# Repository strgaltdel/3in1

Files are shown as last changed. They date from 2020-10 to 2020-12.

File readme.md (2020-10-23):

## 3in1
November 2020

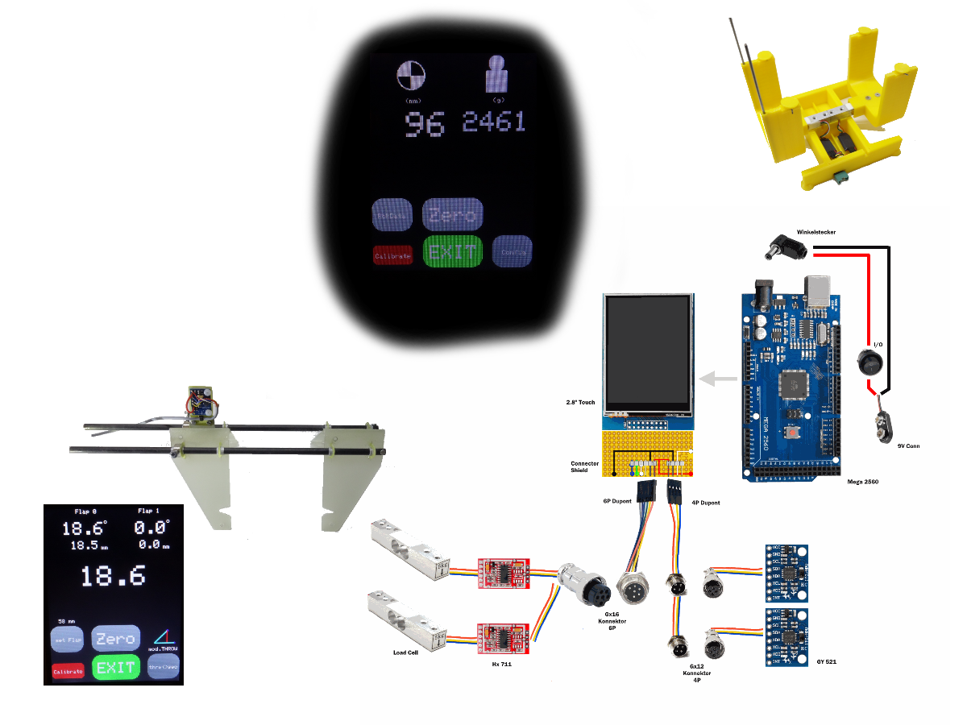
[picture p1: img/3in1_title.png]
3in1 title


### Einführung

"3in1" ist ein Mehrzweck Meßinstrument für den RC Bereich

Basierend auf der Arduino Mega2560 Platform können RC Hobbyisten folgende Werte an Flugmodellen vermessen:

  * Schwerpunkt
  * EWD
  * Ruderausschlag

### Hardware
  
  * Controller
	* Arduino Mega 2560 
  * LCD
	* 2.8" Touch, Adafruit kompatibel
  * Schwerpunkt
	* 2xHX711 basierte Load-cells in 1,2,3 oder 5kg Ausführung
  * EWD
	* GY521 IMU
  * Ruderausschlag
  	* GY521 IMU

### integrierte Funktionen

  * freie Konfiguration der Schwerpunktwaage
  * Kalbrierung der Wägezellen
  * Kalibrierung der IMU Sensoren
  * Verwaltung zweier EWD-HeckSensoren, um Standard und V-Leitwerke vermessen zu können

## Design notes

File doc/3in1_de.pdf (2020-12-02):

November 2020
„3in1“

## Messgerät

by strgaltdel
aka unow
Revision 1.0
- Schwerpunktwaage
- EWD Waage
- Ruderausschlag

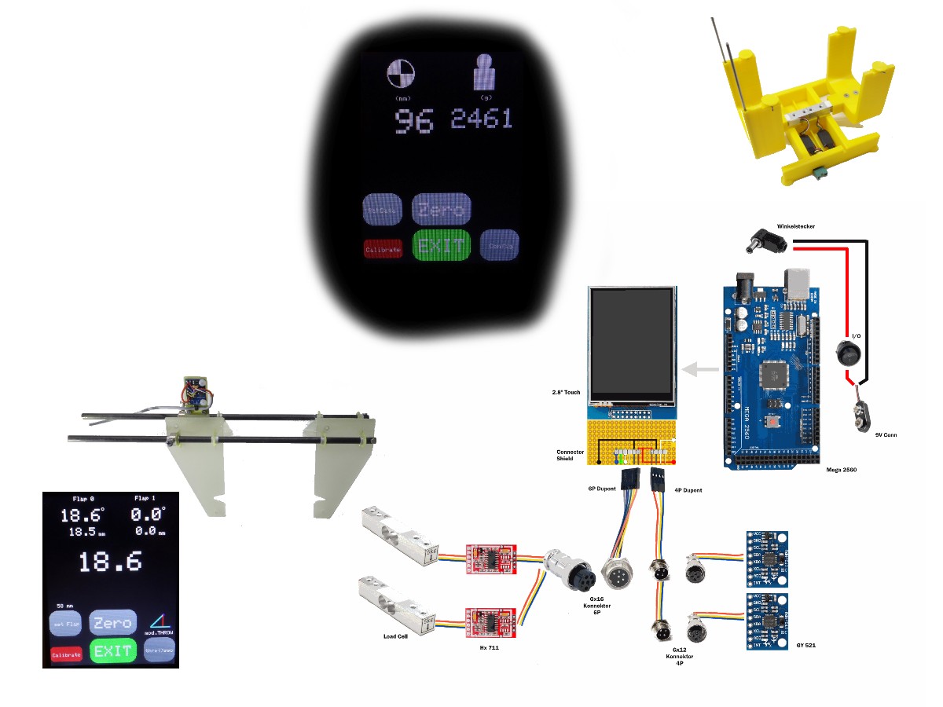
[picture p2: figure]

## Inhaltsverzeichnis

## Allgemeine Intention:

Seit einiger Zeit häufen sich im Flächen-RC Bereich DIY Projekte, die elektronische Schwerpunktwaagen, EWD Messgeräte und Ruderausschlagssensoren vorstellen.

Diese Projekte nutzen häufig gleiche (IMU) Sensoren bzw gleiche oder ähnliche Microcontroller. Abgesehen von den Implementationen, bei denen die GUI auf ein Handy umgesetzt wurde, ist die Bedienmöglichkeit relativ einfach gehalten.

Die „3in1“ Lösung greift die Idee auf, diese Einzelprojekte in ein Gerät in etwa kostenneutral zu vereinen. Anstelle mehrerer kleiner z.B. Arduino-Nano-Microcontroller und einfacher 16x2 LCD Shields wird ein etwas leistungsfähigerer Arduino Mega zur Steuerung sowie ein TFT Touch Panel zur Bedienung verwendet.

Die erweiterten Hardwareressourcen werden genutzt um z.B. die üblicherweise „externe“ Kalibrierroutinen der IMUs zu integrieren und die Ergebnisse ins Eeprom des Microcontrollers abzuspeichern.

Es besteht auch die Möglichkeit zwei unterschiedliche „Heck“ Meßwaagen zur EWD Messung von z.B. konventionellen und zusätzlich V-Leitwerken zu verwalten.

Es verbleiben nach Fertigstellung des Codings noch genügend Ressourcen, um weitere Ideen / Funktionalitäten in der Zukunft umzusetzen.

Das Projekt ist für den Open Source DIY Bereich vorgesehen.

Ich bedanke mich unbekannterweise bei den Entwicklern der bereits existierenden Projekte der RC-Network und RC-Groups Foren, die eine hervorragende Inspiration bei der Umsetzung waren.

Der besondere Dank gilt Paul Poschen für die umfangreiche Entwicklung und Bereitstellung der 3 D Plots.

Dieses Manual gliedert sich zunächst in der Beschreibung zur Bedienung der Oberfläche und danach in eine Anleitung den Arduino zu flashen bzw den Code zu Compilieren,
gefolgt von Hinweisen zum Bau des Meßgerätes (Kopfstation und Meßapparate)

Im Anhang befinden sich Verdrahtungsschemata und Teileliste

Unter Anmerkungen sind ergänzende Hinweise zu bestimmten Komponenten zu finden.

Das Projekt (Coding, Plots..) kann unter folgender Adresse heruntergeladen werden

### https://github.com/strgaltdel/3in1

Eine Übersicht über die Funktionsweise als Video:

### Video: Einführung 3in1 (https://www.youtube.com/watch?app=desktop&v=5wHfVRds9-g)

Hier ein Video, wie die Lagesensoren kalibrert werden:

### Video: Kalibrierung IMU (https://youtu.be/M7ZFKnciECc)

## Komponenten

Das Gerät besteht aus den Komponenten „Headunit“, den EWD Meßschiebern, der Schwerpunktwaage und den Ruderwegsensoren

Headunit
Die Headunit ist die Steuereinheit.
Hier werden alle Sensoren angeschlossen.
Als Microcontroller dient ein Arduino Mega

Die Bedienung geschieht durch ein 2.8Zoll Touch Display
Es wurde ein Typ ausgewählt, der direkt als „shield“ auf die Pfostenleiste des Arduinos gesteckt werden kann.
Die Grösse ist so ausgesucht, daß sie zum einen genügend Fläche und Auflösung besitzt, zum anderen auf dem Arduino noch genügend frei zugängliche Pins übrig lässt um ein Connectorshield aufzusetzen.
Die mit dem Coding getesteten Displays kommen von Banggood (Geekcreit).

Stromversorgung ist durch eine 9V Blockbatterie vorgesehen, es kann via USB eine Powerbank genutzt werden.

Als Gehäuse dient ein DIY 3-d Druck Gehäuse bzw fertige Acrylglas-Arduino Gehäuse, wobei dann aber Controller und Touch Display recht offen liegen.

Als Konnektoren für die Lagesensoren (EWD/Ausschläge) sind GX 12 Stecker vorgesehen
(benötigt werden 4 Pins)
Die Schwerpunktwaage wir über einen GX 16 Konnektor verbunden
(benötigt werden 6 Pins)

Durch diese Wahl wird ein falsches Anschließen von Waage bzw Lagesensoren ausgeschlossen.

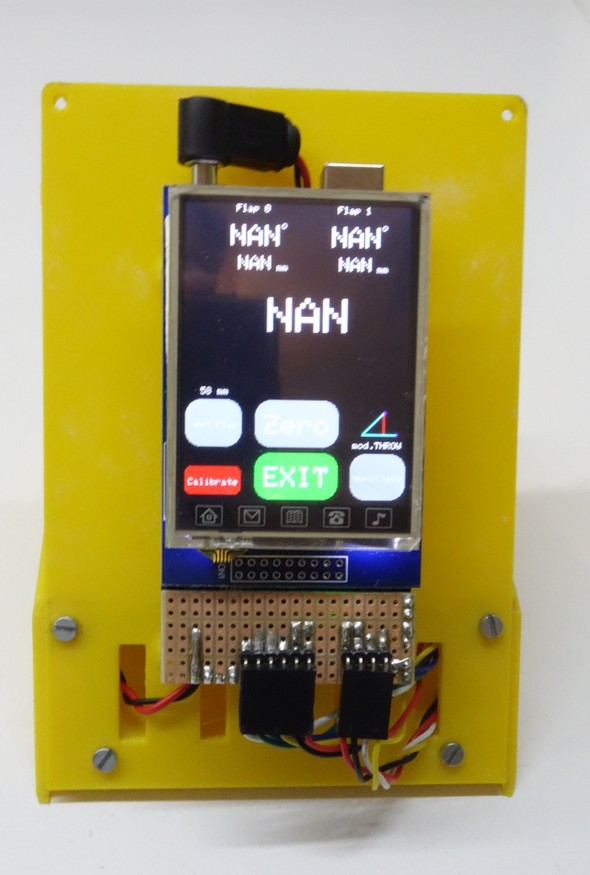
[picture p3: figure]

Bsp mit DIY Gehäuse ohne Front

Schwerpunktwaage

Hier werden bereits bewährte 3d DIY Plots aus den einschlägigen Foren verwendet. Die Waage wird ausgestattet mit den entsprechenden Wägezellen nach Bedarf (typisch 1,2,3,5 kg Meßbereich)
und den dazugehörigen HX511 Boards.

Mehr Elektronik ist in den Waagen nicht notwendig.

Die Verkabelung zur Headunit kann direkt an die HX511 Boards gelötet werden, oder z.B. über einen „Multiplex Stecker“ mit 6 polen trennbar gestaltet werden.
Etliche vorhandene CG Waagen haben Aufnahmen für MPX Steckersystem
Ich persönlich bevorzuge dafür GX Anschlüsse.

Die stl Daten der u.a. Waage sind im Projektverzeichnis abgelegt.
Sie ist etwas stabiler und grösser als die typischen, mit bekannten und wurde durch einen Kollegen im Rahmen des Projektes entworfen.
In der Headunit-Konfiguration muss ein Anschlag von 25mm und die Auflage mit 143mm eingetragen werden.
Die nutzbare (Rumpf-)Breite der Gabeln beträgt 83mm.

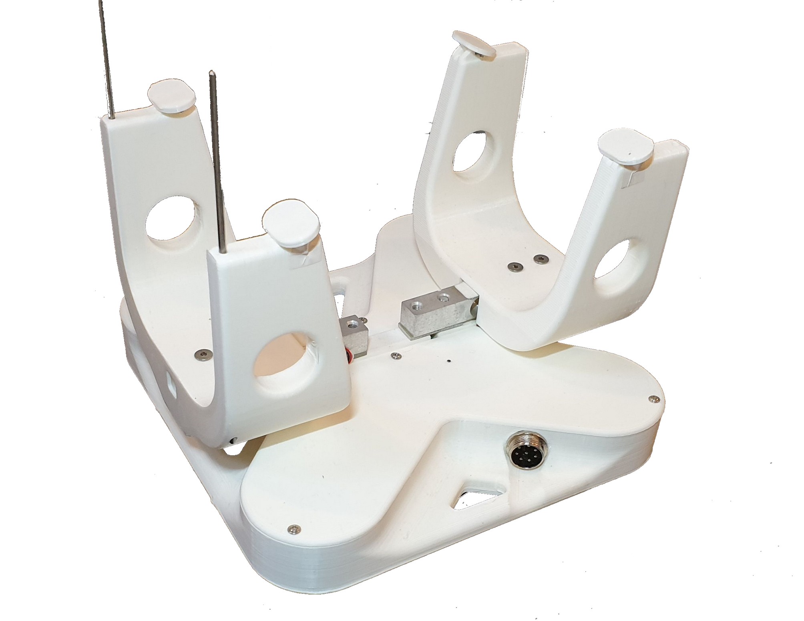
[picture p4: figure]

EWD-Waage

Hier werden bereits bewährte 3d DIY Plots thingiverse einschlägigen Foren verwendet. https://www.thingiverse.com/thing:2938217

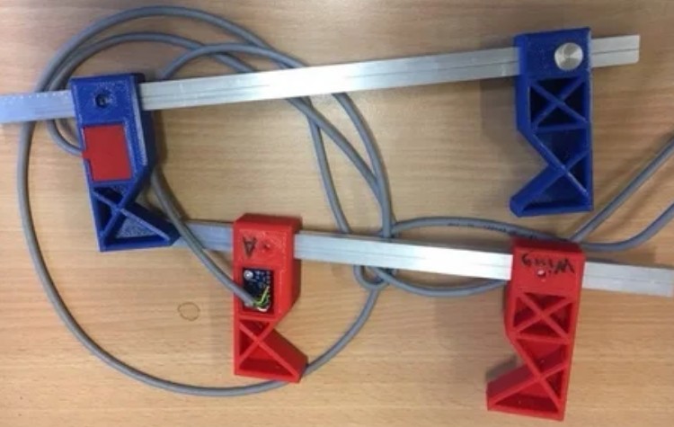
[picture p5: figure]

Die Waage wird ausgestattet mit den entsprechenden Lagesensoren vom Typ „GY 521“.

Für die Verkabelung sollte ein möglichst leichtes und flexibles 4-Draht Kabel verwendet werden. Meine Empfehlung lautet Tonarmkabel.

Für die Messung von V-Leitwerken benutze ich einen Eigenbau.
Das Prinzip funktioniert entsprechend konventioneller EWD Waagen, nur das über eine Art „Prismenschablone“ das Leitwerk eingespannt wird.

Ein Bild sollte die Funktionsweise erklären:

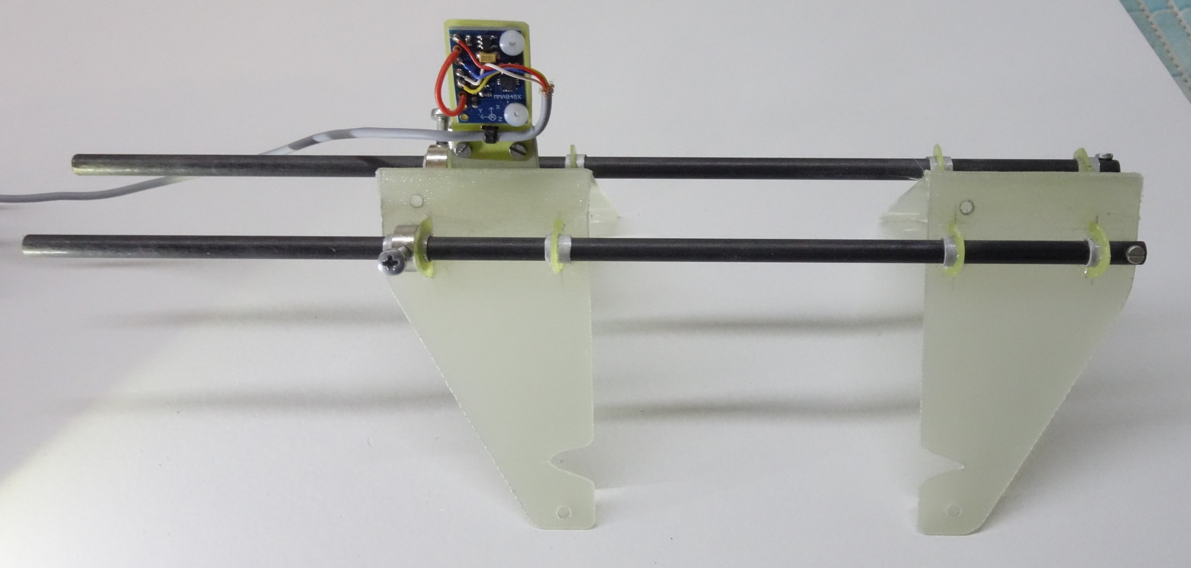
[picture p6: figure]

Wichtig ist, dass die vier Aufnahmepunkte / Aussparungen für Nasen und Endleiste exakt eine Ebene aufspannen.
Für die „Nullung“ vor der Messung ist es ebenfalls wichtig, das alle vier Punkte identische Abstände nach unten zum jeweiligen Auflagepunkt besitzen, da es sonst zu einem Offset zum Flächen-Meßschieber kommt.

Leider gibt es dazu keinen 3d Plot

Ruderwegmessung

Es wird der gleiche GY-521 Sensortypen wie bei den EWD Waagen genutzt.
Es sollte ebenfalls das gleiche Kabel wie zuvor verwendet werden (leicht & flexibel)

Der Sensor wird auf eine Halterung geschraubt, die auf ein Ruderblatt befestigt wird.

Diese Halterung hat etliche Evolutionsstufen durchlaufen

Am Anfang wurde eine Art Klammer verwendet, die ein Kollege entwickelt hatte

letztendlich ist eine simplere Konstruktion geworden, die einfach auf ein Ruderblatt geschoben wird. Auf der Oberseite wird zur Schonung von Oberflächen 1mm dickes Gumi geklebt.
Das untere Blatt besitzt 3mm bzw 4mm Mossgummi, um etwas Anpressdruck zu generieren.

Die offene Platine kann durch eine kleine Abdeckung geschützt werden.
Gleichartige Halterungen können auch mit 1,5mm Sperrholz und etwas Balsa/Abachi gebaut werden.

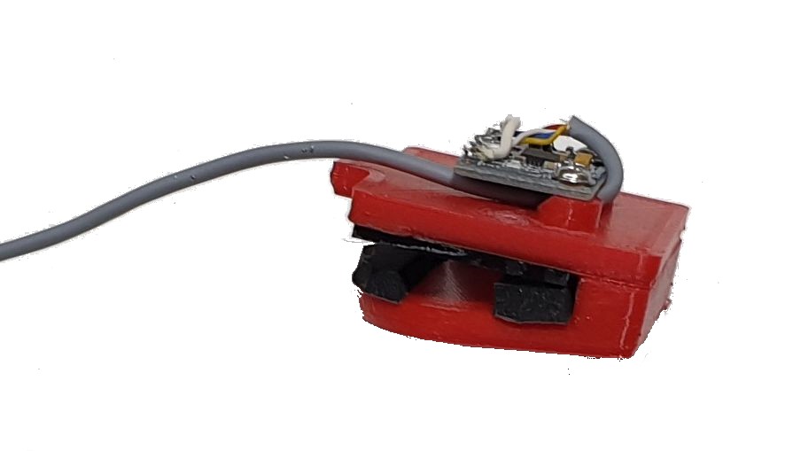
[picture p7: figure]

Hinweis: alternativ kann der Kabelausgang auch „nach hinten“ herausgeführt werden.

## Inbetriebnahme

Vor dem Einschalten müssen die für die jeweilige Messung notwendigen Messgeräte, also entweder

- Waage
- EWD Meßschieber oder
- Ruderweg Sensoren

angeschlossen werden.
Der Microcontroller initialisiert während des Einschaltens die gefundenen Sensoren, so dass ein nachträgliches Anschliessen ggf. zu Problemen führt.

Es muss sichergestellt werden, dass der Arduino mit einer ausreichenden Stromquelle versorgt wird. Der Arduino Mega kann über einen Hohlstecker mittels einer Versorgungsspannung zwischen 7-20V betrieben werden. Alternativ zu einem Steckernetzteil bietet sich z.B. ein 9V Batterieblock an.
Als weitere Möglichkeit kann der Mega auch über den USB Anschluss, z.B. mittels einer PowerBank, gespeist werden.

Aufgrund nicht vorhandener Restwelligkeiten ist eine Versorgung via Batterie/Akku zu empfehlen.

Vor den ersten Messungen müssen die Konfigurationsdaten der Schwerpunktwaage im entsprechenden Menü hinterlegt und die jeweiligen Sensoren über die jeweiligen Menüpunkte kalibriert werden.

## Hauptmenu

Funktion
Nach Einschalten der Headunit und Initialisierung der Sensoren erscheinen die Buttons um die jeweiligen Untermenüs der drei Meßmöglichkeiten zu verzweigen

SP Waage
(Schwerpunktwaage)

Durch Drücken des Buttons wird in das Menü zur Messung von Schwerpunkt und Gewicht verzweigt.

Hinweis:
In der Konfiguration der Schwerpunktmessung kann das Einheitensystem zentral von metrisch auf imperial, also mm<>inch, Gramm<>Unze, umgestellt werden.
Diese Einstellung gilt dann übergreifend für alle Messungen !

EWD
(EWD Messung)
Hier wird in das Menü zur Messung der Einstellwinkeldifferenz verzweigt

Ruder
(Ruderausschlag Messung)
Hier wird in das Menü zur Messung von Ruderausschlägen verzweigt

## Schwerpunktwaage

Anzeige
Die Bedienoberfläche zeigt links oben den Schwerpunkt, rechts oben das Gesamtgewicht an.

Button „Zero“

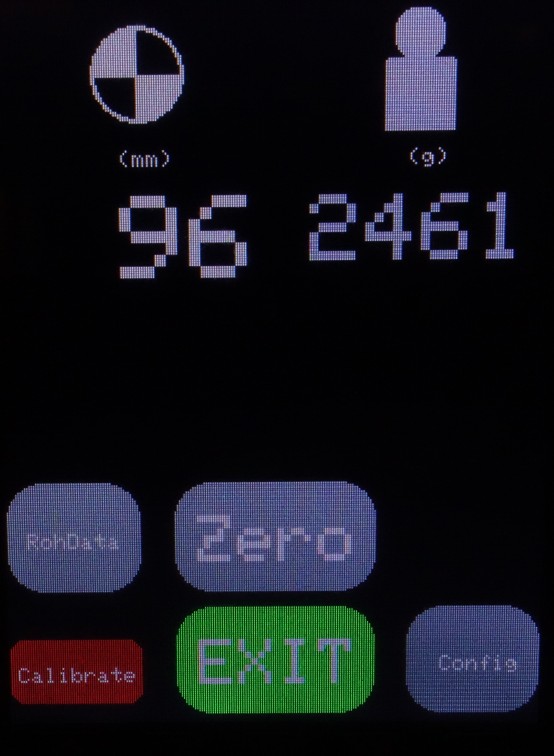
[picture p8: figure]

Vor Nutzung muss mittels „Zero“ das Tara Gewicht ermittelt werden, danach kann das Modell aufgelegt werden und nach kurzer zeit stabilisiert sich Anzeige.

Button „Rohdata“
Über den Button „Rohdata“ erhält man Angaben darüber, wie sich das Gewicht jeweils auf die vordere & hintere Messbrücke aufteilt. Diese Information gibt einen Eindruck davon, ob die für die jeweilige Waage gewählten Kraftsensoren wirklich in einem günstigen (linearen) Meßbereich liegen und nicht schlimmstenfalls eine Messung außerhalb des Endwertes des Sensors vorliegt.

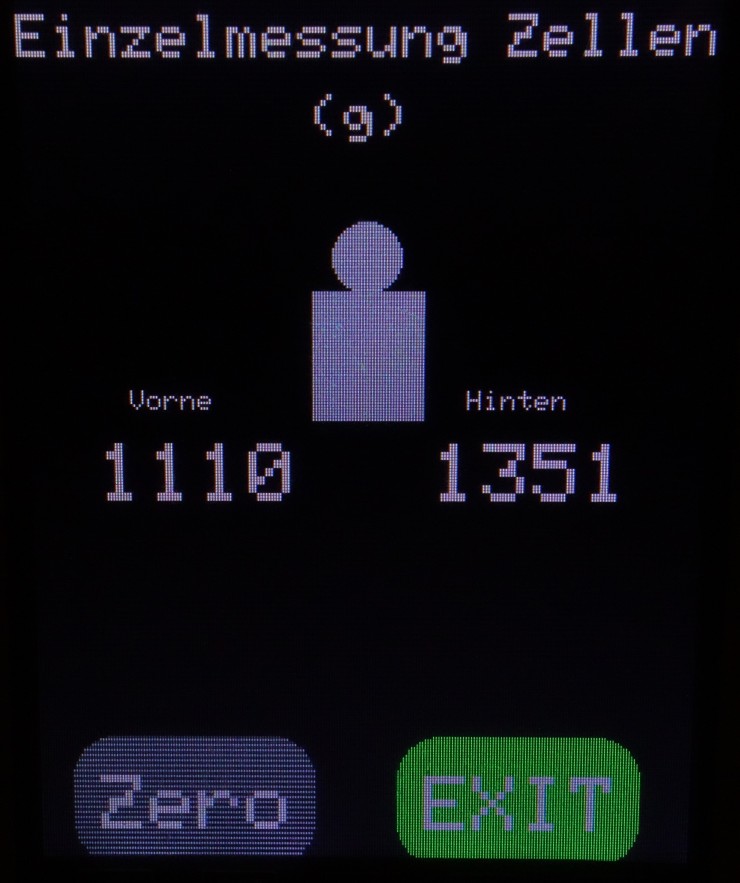
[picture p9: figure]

Button „Exit“
Hiermit wird das Menue verlassen

Button „config“
Das Menü „Config“ ermöglicht es folgende Einstellungen der Waage vorzunehmen:

Auflage

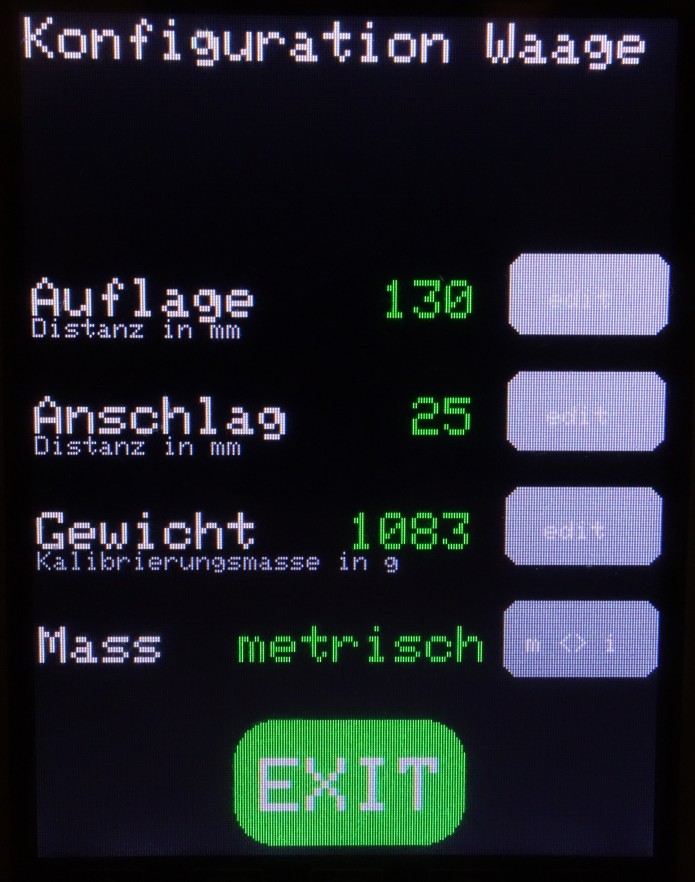
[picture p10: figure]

- der Abstand der Auflagepunkte in Längsrichtung zwischen den Gabeln der Waage.
Meistens haben die Waagen eine bewegliche Auflagefläche, man misst dann den Abstand der Achsen. Eingabe auf 1/10mm möglich bzw. sinnvoll

Anschlag
- der Abstand vom Anschlag der Waage zum vorderen Auflagepunkt
Eingabe auf 1/10mm möglich bzw. sinnvoll

Gewicht
- Masse des Referenzgewichtes, mit dem die Kalibrierung der Wiegezellen durchgeführt wird. Empfehlung: Gewicht sollte in etwa 50%..80% des Messbereichsendwert einer Zelle entsprechen.
Der Korrekturfaktor zur Gewichtsermittlung ist eine float Variable mit durch Anzahl v. Nachkommata begrenzter Genauigkeit. Sollte es bei einer Kontrollmessung zu einer Abweichung von 1..2 Gramm zum Referenzgewicht kommen kann man eine um dieses Delta „falsche“ Kalibriermasse angeben um den Effekt zu kompensieren.

Mass
- Umstellung zwischen metrischen und imperialen Einheitensystem für die gesamte Messeinrichtung.

Edit
- über die edit Taste kann der jeweilige Wert geändert werden

Button „calibrate“

Das Menü „Calibrate“ führt in die Kalibrierungsroutine der Waegezellen.
Dazu benötigt man ein Referenzgewicht, dessen Masse zuvor in der Konfiguration angegeben wurde. Jede Auflagegabel wird zunächst leer, anschliessend mit Referenzgewicht gemessen.
Daraus generiert das Programm die „Kennlinie“ des jeweiligen Meßaufnehmers.
Die Menueführung ist selbsterklärend.
Die Routine kann beliebig oft wiederholt werden.

Folgende Schritte werden nacheinander durchgeführt:

(1) Messung der vorderen Auflage ohne Last
(2) Messung der vorderen Auflage mit Referenzgewichtes
(3) Messung der hinteren Auflage ohne Last
(4) Messung der hinteren Auflage mit Referenzgewichtes

Es versteht sich von selbst, dass die Masse des Referenzgewichtes zuvor unter /config /Gewicht korrekt eingetragen wurde !

## EWD

Funktion
In diesem Untermenue kann die EWD eines Modells vermessen werden. Es müssen zwei Meßsensoren an der Headunit angeschlossen sein.

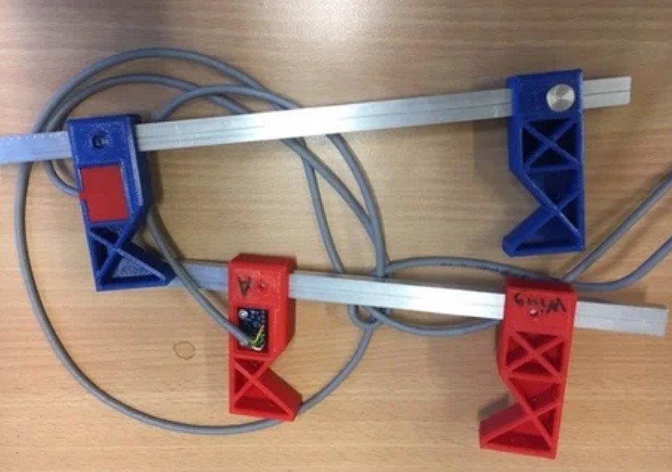
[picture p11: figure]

(Bildquelle: thingiverse)

Zunächst werden die beiden „Meßschieber“ stehend auf eine Ebene Platte gestellt und der Button „Zero“ gedrückt. Damit erreicht man die Referenzierung der „Null Ebene“, also die Messung von 0 Grad bei gleicher Sensorausrichtung.

Danach setzt man den Grösseren Meßschieber an der Fläche an, den kleineren ans Leitwerk.

Die EWD Waage zeigt entsprechend die EWD an.

Die Messung über zwei Schieber hat den Vorteil, dass die Lage des Modell geändert werden kann, ohne die Messung zu beeinflussen.

Die Headunit verwaltet zwei Messchieber für das Leitwerk, um getrennte Schieber für konventionelle und V Leitwerke ansteuern zu können

Anzeige
Die Bedienoberfläche zeigt im oberen Bereich die Einzel-Messergebnisse an.
Zentral wird der Differenzwert in Großschrift dargestellt.

Sollte der Wert ausserhalb typischer Werte (0.5-2.0 Grad) liegen wechselt die Farbe nach rot

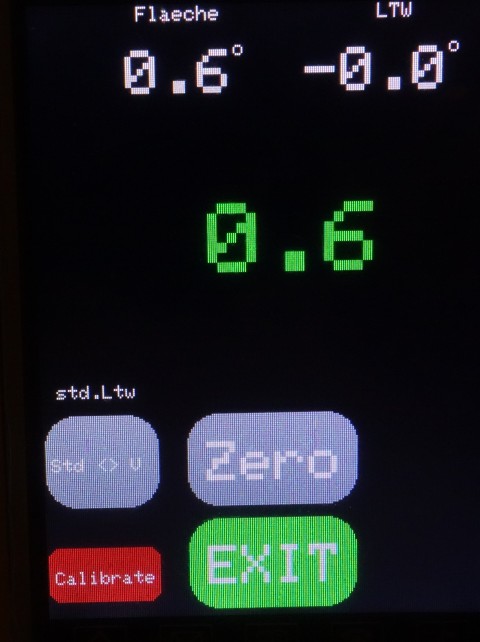
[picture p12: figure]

!! Der Winkel „Fläche“ zeigt den Anstellwinkel, der Winkel „LTW“ ist positiv wenn auf „Höhe“ eingestellt. Die EWD ist also die Summe beider Werte !!
(klassischerweise müsste bei „Höhentrim“ die Anzeige negativ sein)

Button „Zero“
Vor Nutzung muss wie bereits oben beschrieben die Ausrichtung der Meßschieber „synchronisisert“ werden. Dazu werden die Schieber senkrecht auf eine Ebene Fläche gestellt und „Zero“ gedrückt.
Danach sollten die Anzeigewerte um 0,0 herum minimal schwanken („Meßrauschen“)

Button „Std <> V“
Durch den Button „Std <> V“ wird der Leitwerkssensor umgeschaltet zwischen Standard und V-Ltw Messung.
Es werden die jeweils zum passenden Sensor hinterlegten Kalibrierungsdaten angewendet um eine möglichst präzise Messung zu ermöglichen

Button „calibrate“
Das Menü „calibrate“ ermöglicht es die verwendeten Sensoren zu kalibrieren.
Wenn die Kalibrierungsroutine gestartet wurde muss der Sensor um alle drei Achsen in jeweils beide Endpositionen (also links/rechts; vorne/hinten; oben/unten) verbracht werden und pro Position mindestens eine Messung durchgeführt werden.
Mehrfachmessungen einer Position sind möglich.

Die drei gedachten „Achsen“ müssen möglichst exakt, wie in einem karthesischen Koordinatensystem, im Winkel von 90 Grad zueinander stehen.

Am praktikabelsten ist es eine Art Würfel zu benutzen, an dem auf einer Ebene der Sensor planparallel montiert wird.
Dann die Messung „auf allen 6 Flächen“ des Würfels durchführen.

Button „Exit“
Hiermit wird das Menue verlassen

## Ruderweg

Funktion
In diesem Untermenue können die Ruderausschläge eines Modells vermessen werden.
Es können zwei Meßsensoren an der Headunit angeschlossen sein.
Die Meßsensoren sind gleichen Typs wie die EWD Sensoren und können daher mit den gleichen Ports wie die EWD „Schieber“ verbunden werden

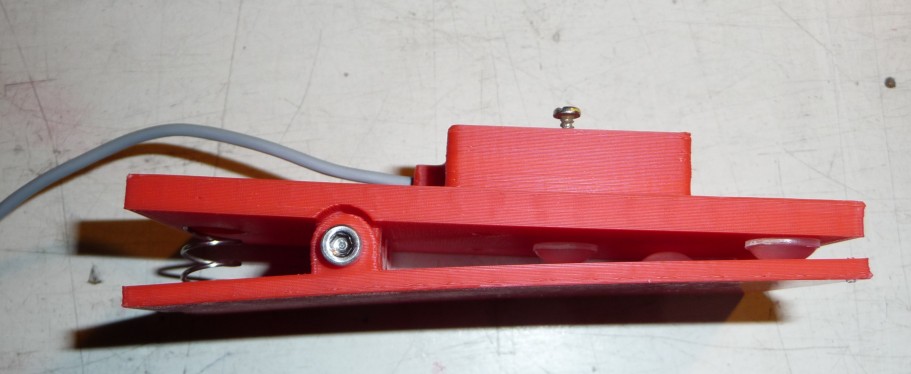
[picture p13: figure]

Idealerweise werden die beiden „Klammern“ zusammen auf eine Ebene Platte „geheftet“ und initialisiert. Damit erreicht man die Referenzierung der „Null Ebene“, also die identische Winkelmessung bei gleicher Sensorausrichtung.

Danach setzt man Klammern an die jeweils zu messenden Ruder.
Die Ruder sollten i.d.R. so eingestellt sein, dass sie identische Winkel anzeigen.
Danach wird nochmals „Zero“ gedrückt um diese Position als Neutralstellung zu reklamieren.

Anzeige

Das Instrument zeigt dann im oberen Bereich entsprechend die Ausschläge / Winkelpositionen der Ruder an. Dargestellt werden Winkel in Grad und Ausschlag in mm (bei metrischer Einstellung)

Im mittleren Bildbereich wird die Winkeldifferenz der beiden Sensoren dargestellt.

Button „Zero“

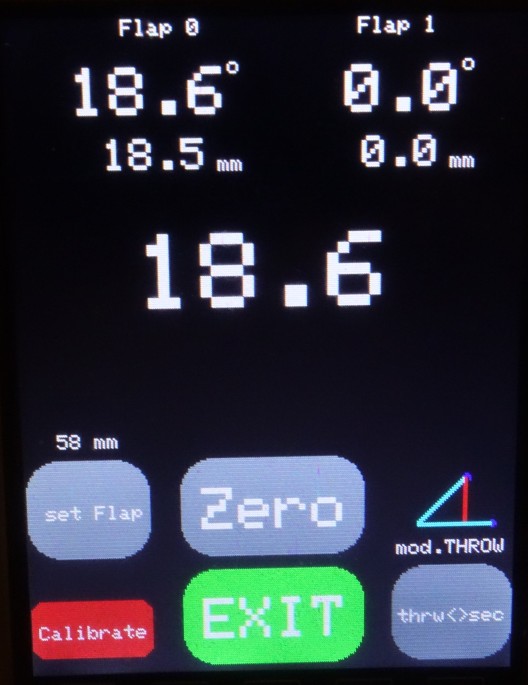
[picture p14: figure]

„initialisiert“ die Sensoren, dass diese Momentanposition als Neutralstellung als 0-Grad Messung zugrunde gelegt wird

Button „set Flap“
Hier kann bei Bedarf die Rudertiefe angegeben werden um eine Ausschlagsmessung als Strecke (Weg nach oben / unten) kalkulieren zu können

Button „thrw<>sec“
Wahl der Wegmessung als „Sekante“ bzw „Tangente“

Button „calibrate“
Das Menü „calibrate“ ermöglicht es die verwendeten Sensoren zu kalibrieren.

Wenn die Kalibrierungsroutine gestartet wurde muss der Sensor um alle drei Achsen in jeweils beide Endpositionen (also links/rechts; vorne/hinten; oben/unten) verbracht werden und pro Position mindestens eine Messung durchgeführt werden.
Mehrfachmessungen einer Position sind möglich.

Die drei gedachten „Achsen“ müssen möglichst exakt, wie in einem karthesischen Koordinatensystem, im Winkel von 90 Grad zueinander stehen.

Am praktikabelsten ist es eine Art Würfel zu benutzen, an dem auf einer Ebene der Sensor planparallel montiert wird.
Dann die Messung „auf allen 6 Flächen“ des Würfels durchführen.

Button „Exit“
Hiermit wird das Menue verlassen

## Aufbau

### Arduino flashen, die einfache Methode

Häufig tauchen bei etwas komplexeren Arduino Projekte Probleme beim Compilieren auf, weil Bibliotheken nicht oder in falscher Version, oder von falscher Quelle heruntergeladen wurden.

Sollte kein Bedarf vorhanden sein den Quellcode individuell anzupassen, ist die schnellste Methode zum Erfolg einfach nur das benötigte Hex (binary) File direkt auf den Arduino hochzuladen.

Ich habe daher zwei Hex-Files im Ordner „bin“ abgelegt.

Das „std“ läuft auf dem „Banggood“ Display mit gelber Stiftleiste (TFTTYPE 2 in der Datei lcd_config.h) ,

https://www.banggood.com/de/2_8-Inch-TFT-LCD-Shield-Touch-Display-Screen-Module-Geekcreit-for-Arduino-products-that-work-with-official-Arduino-boards-p-989697.html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

das „set“ läuft auf dem banggood Display (Stand Nov.2020), das als set inklusive Arduino Uno & 2.4“ Display kommt (TFTTYPE 1) ,
!! in der Vergangenheit wurde durch BG der Displaytyp bereits ein oder zweimal getauscht !!

https://www.banggood.com/de/Geekcreit-UNO-R3-Improved-Version-+-2_8TFT-LCD-Touch-Screen-+-2_4TFT-Touch-Screen-Display-Module-Kit-Geekcreit-for-Arduino-products-that-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

Das „Set-TFT“ besitzt einen Widerstand zur Strombegrenzung, das obige / gelbe Stiftleiste einen Regler.

Der Upload der bins auf den Maga2560 erfolgt mit wenigen Klicks durch das Programm „XLOADER“ https://github.com/binaryupdates/xLoader

### Code Compilieren und Arduino flashen

Wer den Code anpassen und compilieren möchte muss die üblichen Schritte für die Arduino-IDE Entwicklungsumgebung durchführen:

(1)
Der Source Code bzw. die Quelldateien werden in ein Projektverzeichnis kopiert.
Das Verzeichnis muss den gleichen Namen wie das Hauptprogramm besitzen (hier „3in1“)

(2)
Alle notwendigen Zusatz-Bibliotheken (libraries) müssen der IDE zur Verfügung gestellt werden. Ein erfolgreiches Kompilieren ist sonst nicht möglich.

Ein Weg ist es über den Bibliotheksmanager zu gehen,
ein anderer der direkte Download, Entpacken und Kopieren in das Bibliotheksverzeichnis.

Die notwendigen Bibliotheken werden in der „3in1“ App durch die Datei „includes_main.h“ in das Coding eingebunden.

Hier Auszugsweise die notwendigen „addon“ Bibliotheken sowie deren Quellenangaben

#include <Wire.h> | // imu communication | https://github.com/jrowberg/i2cdevlib

#include <TouchScreen.h> | // touch support | https://github.com/adafruit/Adafruit_TouchScreen

#include <Adafruit_GFX.h> | // used for rounded buttons | https://github.com/adafruit/Adafruit-GFX-Library

#include <MCUFRIEND_kbv.h> | // flexible lcd support | https://www.arduinolibraries.info/libraries/mcufriend_kbv

#include <Filters.h> | // Filter classes for smoothing IMU data | https://github.com/JonHub/Filters/blob/master/Filters.h

#include <HX711.h> | // load cell support | https://github.com/bogde/HX711

#include <MovingAverage.h> | // simple way to build moving avg/used in cg | https://github.com/sofian/MovingAverage

#include <I2Cdev.h> | // some i2c, mpu6050 required methods | https://github.com/jrowberg/i2cdevlib

Wurden alle notwendigem Zusatzbibliotheken eingebunden sollte der Compiliervorgang fehlerfrei durchlaufen.
Der Arduino Mega kann geflasht werden.

Anmerkung:
In einer aktuellen Version der Adafruit-GFX lib kam es bei mir zu einem Compilierfehler da die Adafruit_I2CDevice.h Datei nicht existierte.
Ursache ist ein include in den oled libs, es reicht die beiden Dateien „Adafruit_GREYOLED…“ umzubenennen, damit diese nicht mit eingebunden werden.
Die Dateien sind für dieses Projekt nicht notwendig

### Zusammenbau Headunit Gehäuse

Das für das Projekt durch P. Poschen entwickelte Gehäuse wurde auf effizientes Plotten hin optimiert. Die Einzelteile sind von der Konstruktion so gestaltet, dass möglichst geringe Druckzeiten notwendig sind. Daher ist eine Klebung von zwei Deckeln und einem Distanzstück notwendig.
Als Klebstoff kommt Sekundenkleber bzw UHU hart zum Einsatz

Zuvor muss das das „Connectorshield“ angefertigt worden sein, Verdrahtung siehe unten.
Das Connectorshield sollte auf einer „3er“ oder durchgehenden Lochstreifenplatine aufgebaut werden. Bei der Auswahl der gewinkelten Stiftleiste ist darauf zu achten, das sich die Abstandshalter aus Kunststoff auf der Anschlussebene, und nicht an der Lötebene befinden.
(1) Frontblende verkleben
Zunächst wird die Frontblende auf den zugehörigen Rahmen verklebt
Anschliessend der Distanzbolzen, der die Frontblende im unteren Bereich mit dem Sockel verschraubbar macht, in die vorgesehene Position verklebt.

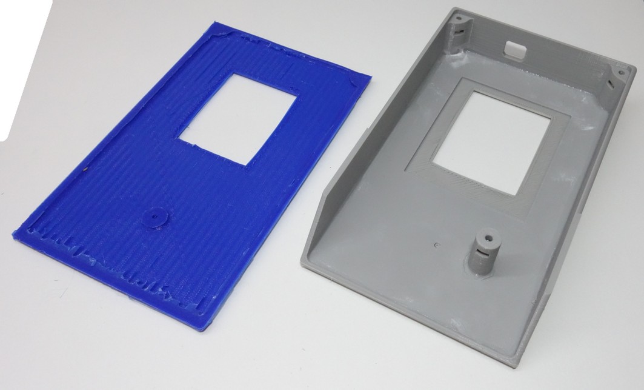
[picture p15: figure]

(2) Sockel mit Deckel verkleben
Nun kann der Deckel (das Teil mit der Batteriehalterung für 9V Blockbatterien) mit dem Sockel verklebt werden.

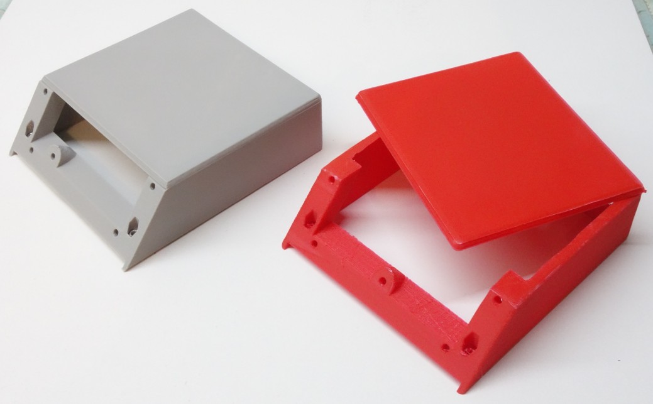
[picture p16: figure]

(3) Rückwand (Arduino Halterung) mit Sockel verschrauben
Es werden vier M3 Muttern in die vorgesehenen Positionen des Sockels geschoben (ggf mit Sekundenklebstoff fixiert), anschliessend wird die Rückwand mit dem Sockel verschaubt

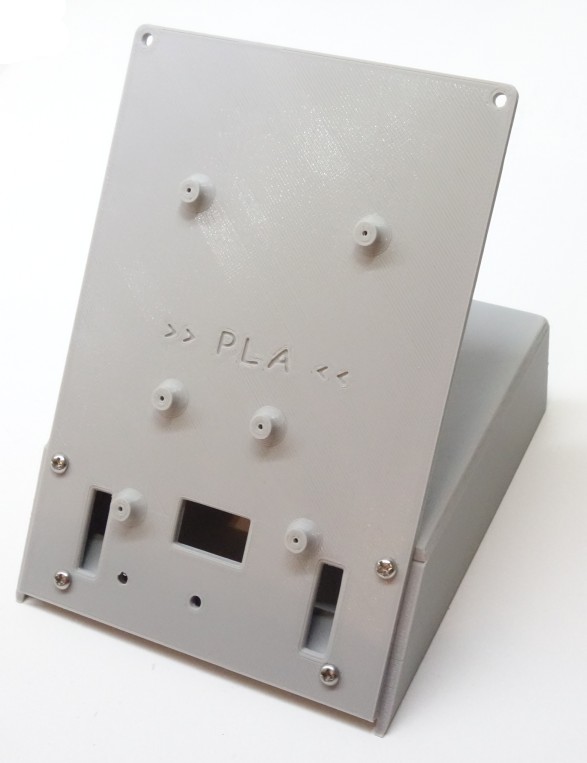
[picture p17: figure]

(4) Ardunino auf Rückwand schrauben
(5) Display und Connector shield auf den Arduino Mega stecken
(6) Stromversorgung
Hohlstecker mit Ein-/Auschalter und 9V Batteriekabel verlöten Schalter einbauen

Zwischenergebnis:

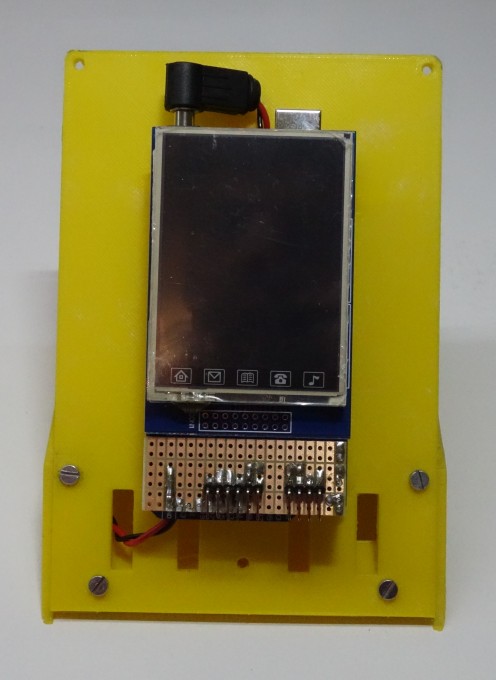
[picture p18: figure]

(7) GY 521 Verkabelung (Ruder & EWD Messung)
4pol Kabel mit Dupont Stecker auf die erste Gx12 Buchse löten & Kabel an den zweiten Connector weiter verlöten
GX12 Buchsen einbauen und verschrauben
Alternativ kann auch anstelle der Steckverbindung direkt auf das shield gelötet werden.
(8) HX 711 Verkabelung (Schwerpunktwaage)
6pol Kabel mit der GX16 Buchse verlöten
GX16 Buchsen einbauen und verschrauben
(9) Verbindungen herstellen
Alle Stecker aufstecken & Funktionstest durchführen

Zwischenergebnis (Perspektive von unten auf den Sockel):

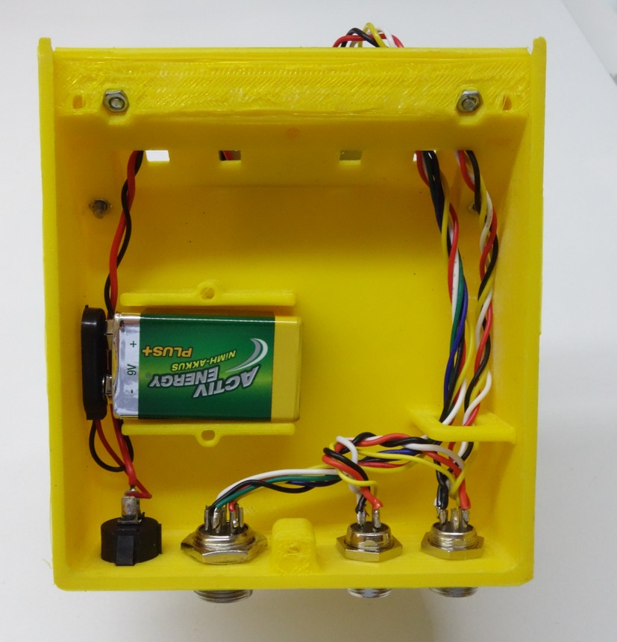
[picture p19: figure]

(10) Frontblende mit zwei M3 Verschaubungen oben, und einer M3 Verschraubung unten befestigen.
Die M3 Verschraubung unten erfolgt schräg durch den Sockel, in den Aufnahmen der Frontblende befinden sich Platzierungen für M3 Muttern
(11) Bodenelement mit Sockel verschrauben und Gummifüsse aufkleben - Fertig -

Verkabelung (extern)

(1) Schwerpunktwaage

An der „Headunit im Gehäuse“ kommt ein GX16 Stecker zum Einsatz.
Verwendet man den Mega2560 im Acryl-Gehäuse ist der Phantasie keine Grenze gesetzt.

Es werden 6 Litzen benötigt, eine Länge von ca einem Meter hat sich bewährt.
Wie immer sind flexible Kabel bei der Handhabung angenehmer.
Als Modellflieger hat man meistens 3 adrige Servokabel als Meterware vorrätig (am besten Silikonkabel), diese sind gut geeignet.
Optisch „netter“ sind komplett ummantelte Kabel. Da keine hohen Ströme fließen bieten sich Signalkabel mit geringem Querschnitt an. Ein gutes Beispiel dafür sind Patchkabel aus dem Netzwerkbereich.
Aber Achtung, es gibt hier von starr bis einigermassen flexibel erhebliche Unterschiede in der Biegesteifigkeit.

Die einfachste Art die Schwerpunktwaage mit der Headunit zu verbinden ist es, das Kabel direkt an die HX711 Sensorplatine zu löten.
Alternativ kann man am Durchbruch der Schwerpunktwaage auch z.B. eine MPX Steckverbindung einsetzen.

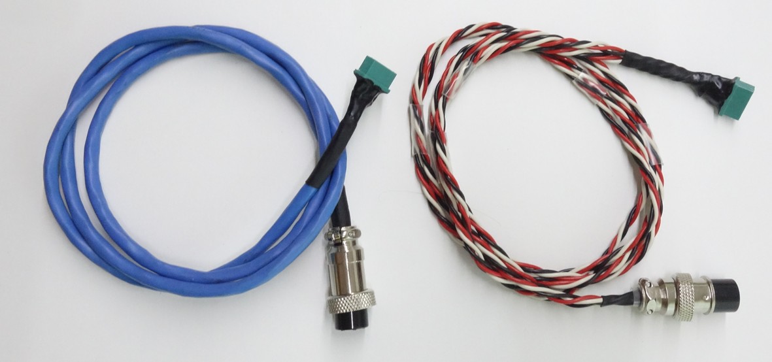
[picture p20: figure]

(2) EWD und Rudersensoren

An der „Headunit im Gehäuse“ kommt ein GX12 Stecker zum Einsatz.
Es werden jeweils 4 Litzen pro Sensor verwendet.
Die Länge sollte den jeweiligen Modellgrössen entsprechend angepasst sein, rnd 80 cm sollten für EWD Messungen ausreichen, 1...1,6 Meter sind typisch für Rudermessungen z.B. für Seglermodelle bis 5m Spannweite

Das Kabel sollte besonders leicht & flexibel sein, um bei Ruderbewegungen bzw. EWD Messungen keine Verfälschungen der Meßwerte zu verursachen.
Besonders empfehlenswert sind z.B. Tonabnehmerkabel.

## Anhang

### Komponentenübersicht

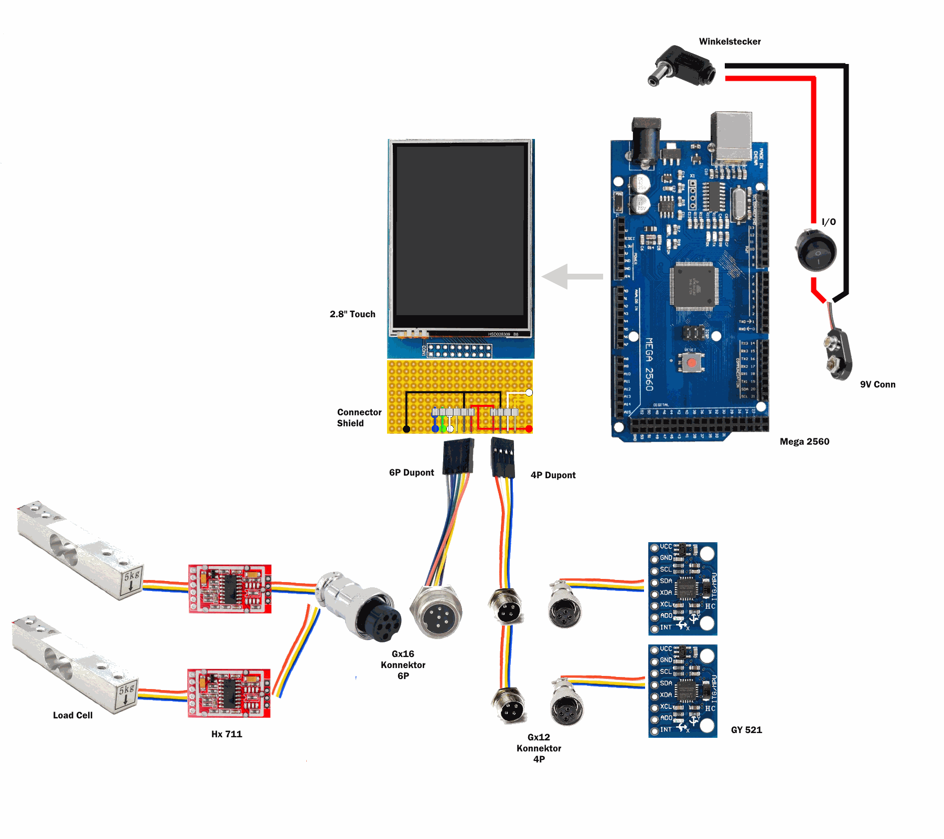
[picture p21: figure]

### Verdrahtungsschema Connector Shield

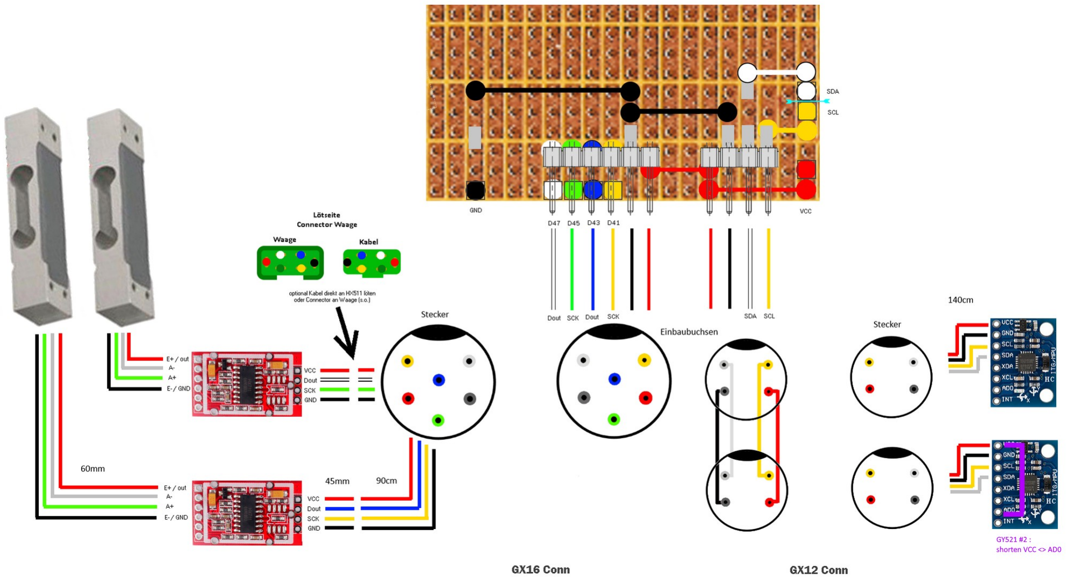
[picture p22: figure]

!! jeweils zweiten GY521 Sensor (IMU) wg Adressierung zwischen VCC und AD0 brücken !!

## Teileliste und Kostenabschätzung „3in1“

### (Vorschlag)

hier eine Teileliste mit Vorschlägen zur Bezugsquellen
Preise sind „Beschaffungskosten“ inkl. übliche Versandkosten, Stand Q4 2020

Bitte nur als Anhaltspunkt verstehen, kann sich jederzeit ändern. Hinzu kommen noch Kosten für den 3d Druck

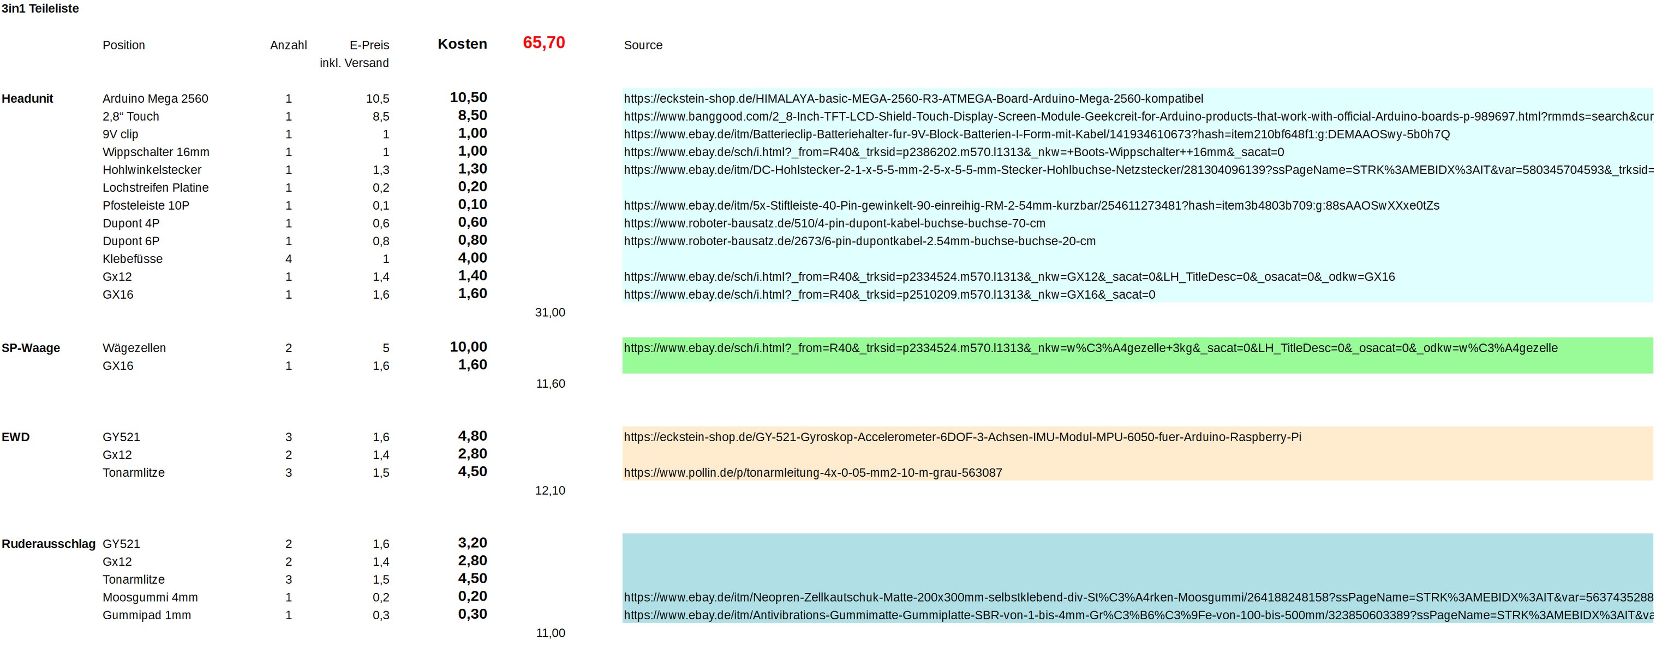
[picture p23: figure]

## Anmerkungen

Allgemein
Ein DIY Projekt motiviert schnell dazu die eigenen Ideen an vorhandene Vorschläge anzupassen oder Verbesserungen vorzunehmen.
Man sollte diese Veränderungen imho in Abhängigkeit der eigenen Kompetenz umsetzen, sonst veriirt man sich schnell in Themengebiete, die einem nicht liegen und das „Projekt“ verliert schnell seinen Reiz.

Daher ein paar Anmerkungen zu ein paar Themengebiete, die einem das Leben ggf. erleichtern können.

Touchdisplay

Es gibt eine Vielzahl unterschiedlichster Touch Displays auf dem Markt.
Die Konfiguration der Ansteuerung und Treibervielfalt ist dementsprechend.
Ich kann nur empfehlen die beiden von mir getesteten Panels zu verwenden, wenn man noch nicht viel Übung im Umgang mit Arduinos besitzt.
Weitere Displays supporte ich zunächst nicht.

Wer andere Panels verwenden möchte sollten zumindestens darauf achten, dass sie über „Adafruit_GFX.h“ und „TouchScreen.h“ ansteuerbar sind.

Die Beispielprogramme der Hersteller zeigen meist, wie die Panels zu konfigurieren sind. Diese Konfig wird in der Datei „lcd_config“ übernommen
Üblicherweise müssen diese Parameter angepasst werden:

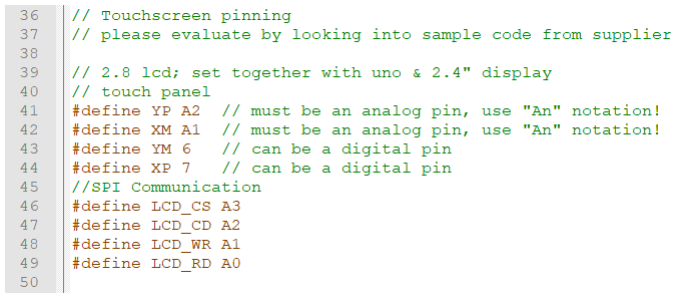
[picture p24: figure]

Sollte ein Touch Display neu kalibriert werden müssen (Unterlagen & Software des Anbieters zu Rate ziehen !“), so sind die neuen Kalibrierdaten zu hinterlegen:

Das

Touch/Tipp-Verhalten kann bei Bedarf an in der Datei „touch.h“ angepasst werden

GY 521 / MPU6050

Der Gy521 ist ein IMU Sensor mit hoher Auflösung und sehr gutem Preis/Leistungsverhältnis

In der Vergangenheit waren “günstige China Boards“ leider häufig falsch bestückt, was ein deutliches Rauschen zur Folge hat.
Ob man damit leben kann, ist eine individuelle Entscheidung.

Erkennbar wird der Effekt an den unruhigen Werten bei Winkelmessungen.
Alternativ berechnet man die Varianz/Streuung einer Meßreihe.
Der Rohdaten Meßbereich liegt zwischen +/-16384, typische Varianzwerte bei ca 55.
Ich persönliche tausche bei Varianzen > 70 den u.a. Kondensator aus:

Um das Rauschen zu minimieren wird einen SMD Kondensator ausgelötet und gegen einen mit 100nF Kapazität getauscht.
Dazu sind entsprechende Lötkenntnisse Voraussetzung

https://forum.arduino.cc/index.php?topic=394691.0

Es kommen für EWD und meistens für die Rudermessung immer zwei Sensoren gleichzeitig zum Einsatz.

Der zweite Sensor (Leitwerkssensor , zweites Ruder) muss über den Arduino über eine zweite Adresse angesprochen werden können

Daher müssen alle zweiten Sensoren zwingend mit einer Brücke zwischen VCC und AD0 ausgestattet werden

Wiegezellen

In Foren ist hin & wieder das Problem aufgetreten, dass die eigentlichen Zellen Unterschiede in den Gewindeaufnahmen besaßen.

Der gängige Typ hat „innen“, an der Festmontage, M5 Gewinde,
die Gabel wird durch M4 Schrauben befestigt.
Es sind auch Zellen im Umlauf, die durchgängig M4 Gewinde (mit meist anderer Positionierung) aufweisen.

HX511:
Hier gibt es Platinen mit unterschiedlichen Qualitätsstufen.
Bewährt haben sich Platinen, die typischerweise rote PCBs besitzen.

Bei ordnungsgemässer Montage haben sich die Zellen als erschreckend genau erwiesen.
Belastet mit 80% der ausgewiesenen Maximalkapazität betrug die Genauigkeit (sorgfältige Kalibierung vorausgesetzt) 1-2 Gramm.

Selbst bei nur 10% Last 2-3 Gramm.

Idealerweise wird der Schwerpunkt des Kalibriergewichtes i.e. zwischen den beiden Verschraubungen der Gabel positioniert.
Eine Abweichung davon um +/- 1cm brachte allerdings auch keinen Unterschied.
Wichtig ist es, darauf zu achten, dass keinerlei Kontakt zu den „starren“ Konstruktionselemten der Waage existiert.

3D plots

Die ideale Lösung ist der 3 Plot für die Headunit (STL Dateien im Ordner \plots\headunit , der Schwerpunkt bzw EWD Waage sowie den Klammern für die Rudermessung.

Nicht jeder besitzt einen 3d Drucker, oder hat Freunde die dies übernehmen können.

Alternativen:

- Headunit:
hier kann als einfache Lösung ein Plexiglas/Acryl Gehäuse für den Arduino Mega verwendet werden, auf dem die shield einfach „offen“ aufgesteckt werden
(s.a. eckstein-shop, ebay …)
- EWD Waage

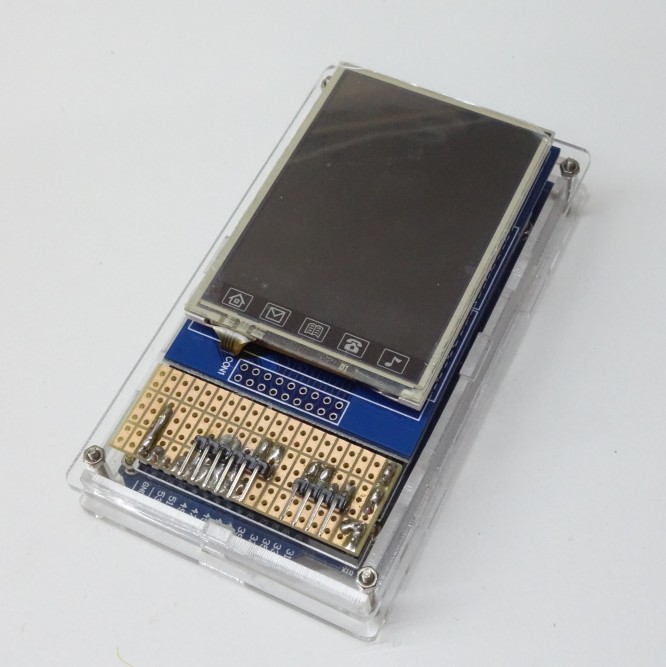
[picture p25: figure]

falls vorhanden, können vorhandene Waagen / Messchieber mit dem GY 521 Sensor ausgestattet werden

- Rudermessung
hier sind durchaus Möglichkeiten durch Eigenbau ohne 3D drucker gegeben,
s.a. https://www.rc-network.de/threads/ruderweg-messung-mit-arduino.639364/page-33#post-7298236
- Schwerpunktwaage
„Ausserhalb“ der 3d Plot Varianten sind mir nur Varianten für den „schweren“ Einsatz, erstellt aus Aluprofilen bekannt.

Die meisten Waagen aus den einschlägigen Foren wiesen eine für mich eher knappe Gabelweite auf.
Der Kollege und Freund Paul Poschen hat daraufhin eine etwwas grössere, stabile Ausführung mit 100mm Weite entwickelt.
Der Anschlag kann konventionell mit Stahlstiften oder alternativ mit variablen Anschlägen für Modelle mit starker Pfleilung ausgeführt werden.

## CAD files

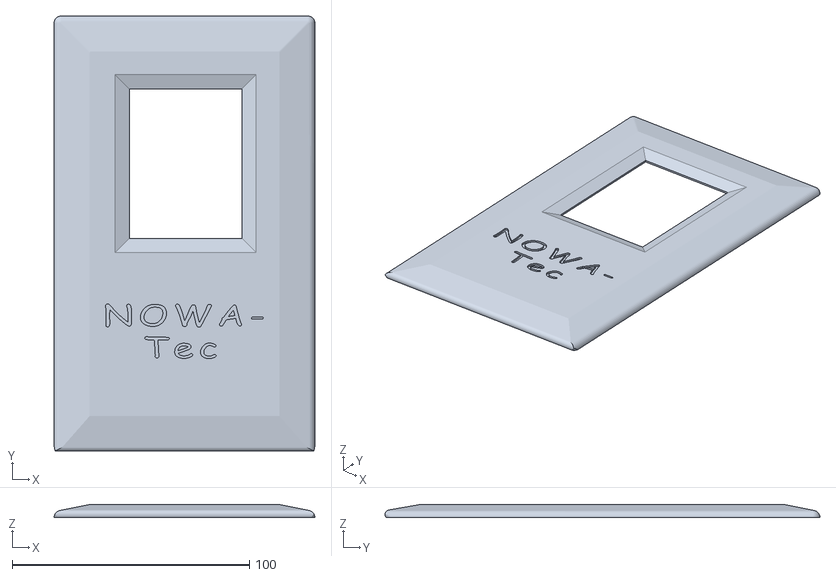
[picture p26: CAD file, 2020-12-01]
stl/Headunit/Frontplatte.STL
110.0 x 183.4 x 5.46

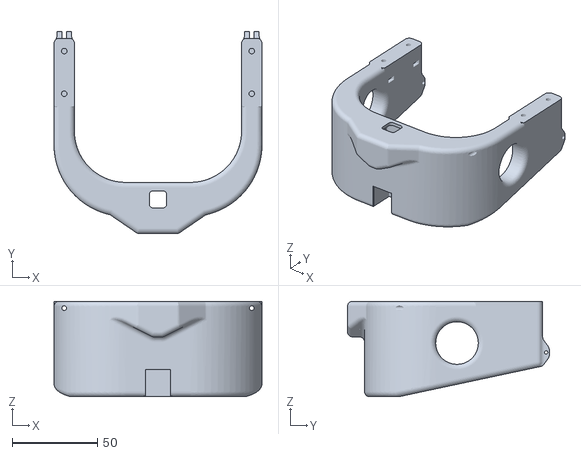
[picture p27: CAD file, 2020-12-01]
stl/Schwerpunkt/Vorderer Modell-Traeger.STL
122.0 x 118.5 x 56.0

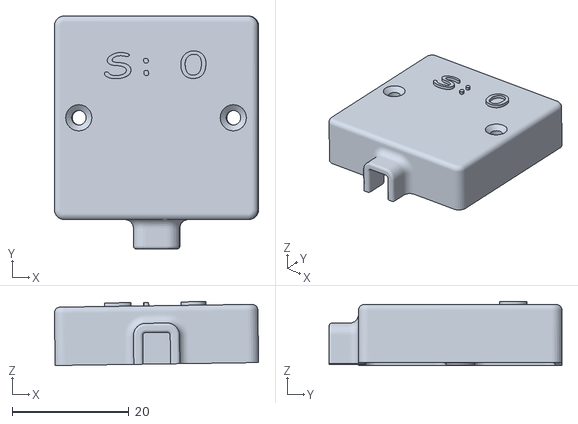
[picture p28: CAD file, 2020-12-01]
stl/Winkelmessung/Deckel S0.STL
35.0 x 39.9 x 11.0

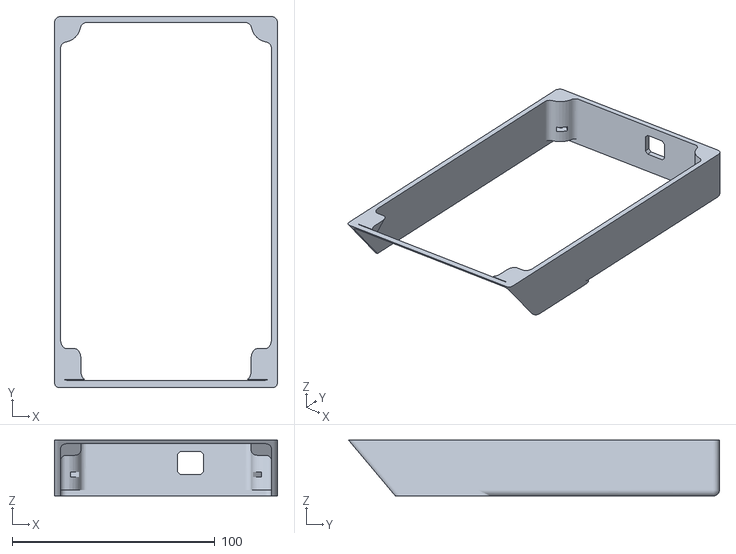
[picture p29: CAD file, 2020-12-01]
stl/Headunit/Displarahmen.STL
110.0 x 183.0 x 27.5

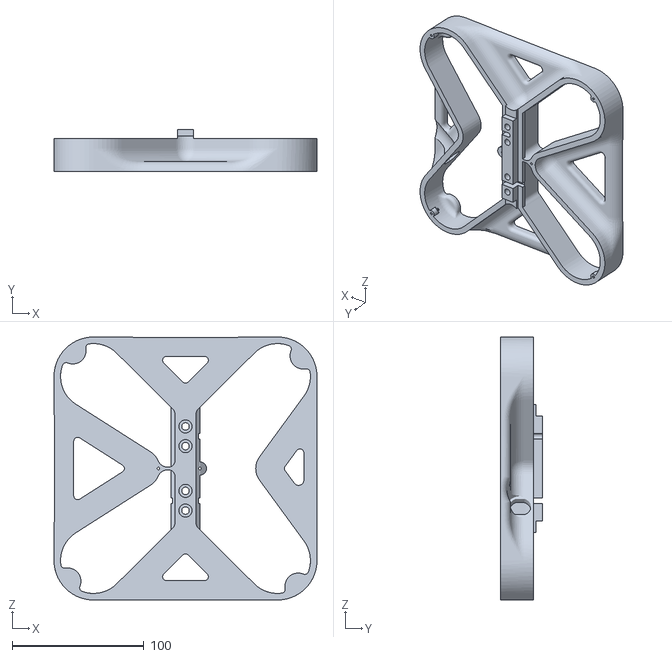
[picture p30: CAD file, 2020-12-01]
stl/Schwerpunkt/Grundkoerper.STL
200.0 x 32.0 x 200.0

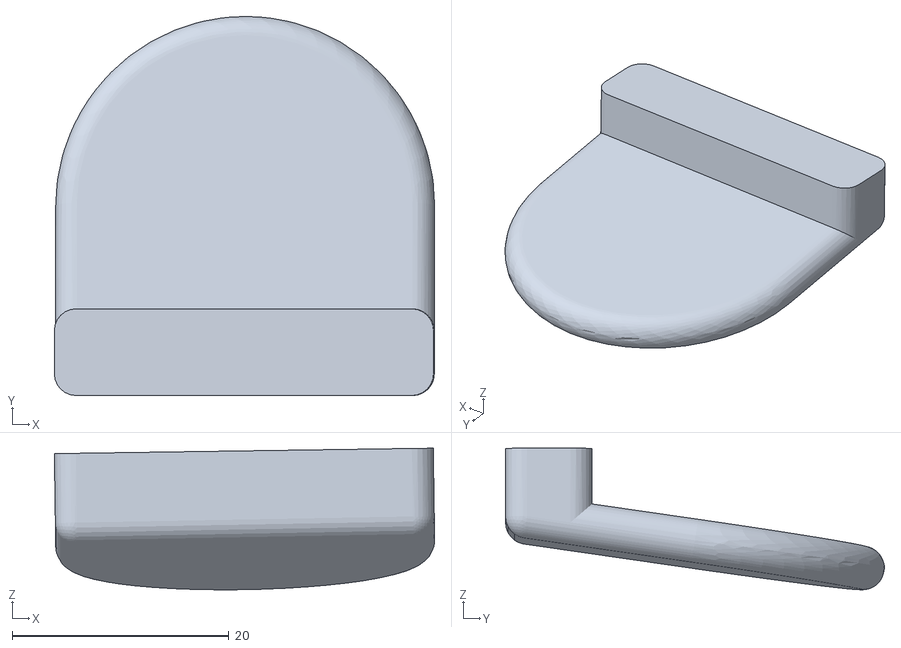
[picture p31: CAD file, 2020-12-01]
stl/Winkelmessung/Sensorgegenplatt.STL
35.1 x 35.0 x 13.1

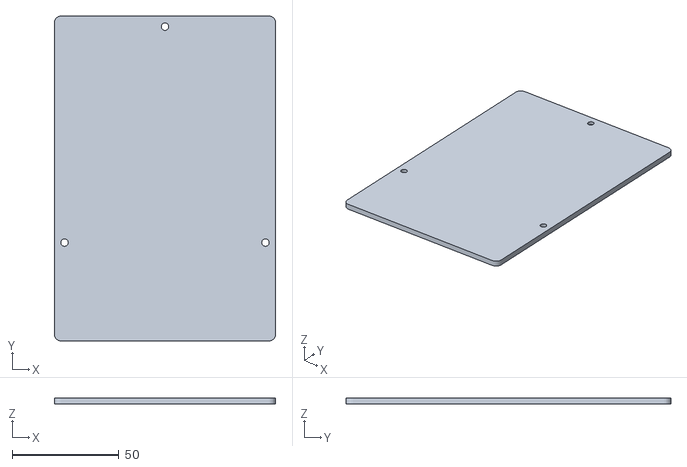
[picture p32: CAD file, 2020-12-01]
stl/Headunit/Bodenplatte.STL
103.6 x 152.1 x 3.00

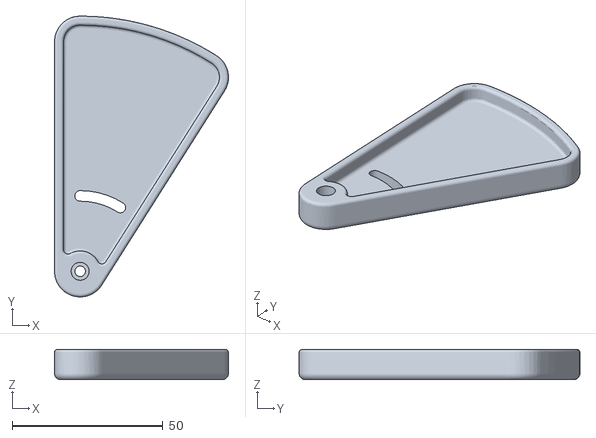
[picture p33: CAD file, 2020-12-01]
stl/Schwerpunkt/Nasenleisten-Anschlaege.STL
57.7 x 93.1 x 10.0

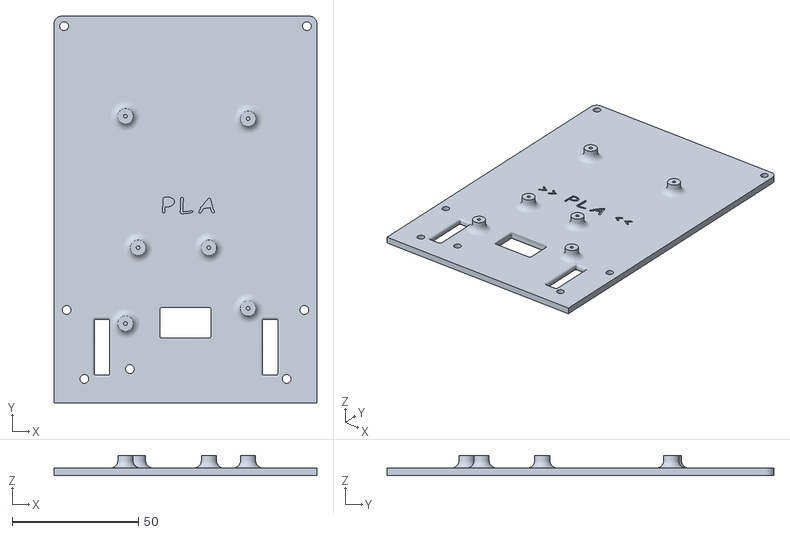
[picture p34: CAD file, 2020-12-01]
stl/Headunit/Display Rueckwand.STL
104.0 x 153.0 x 8.00

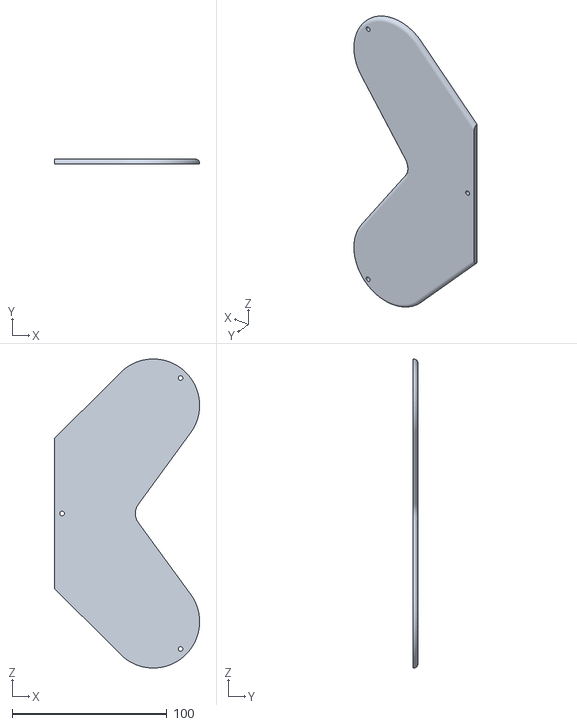
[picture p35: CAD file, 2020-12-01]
stl/Schwerpunkt/Gehaeusedeckel rechts.STL
94.0 x 3.00 x 200.0

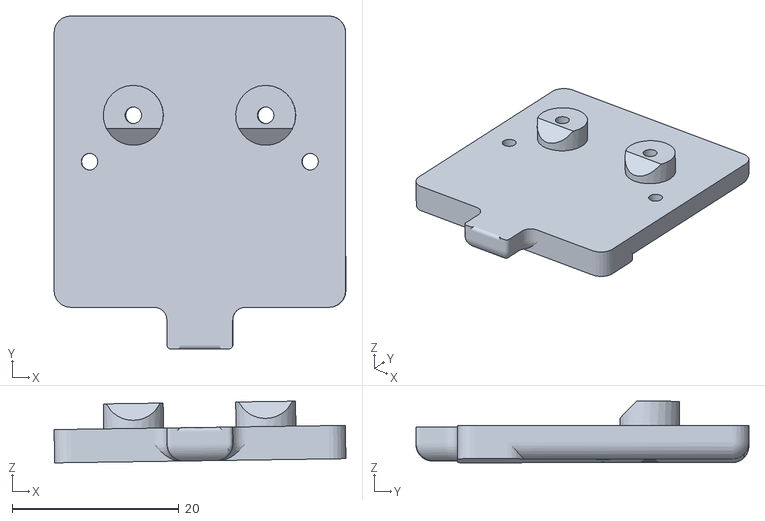
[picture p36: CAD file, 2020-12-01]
stl/Winkelmessung/Sensorgundplatte.STL
35.1 x 40.0 x 7.42

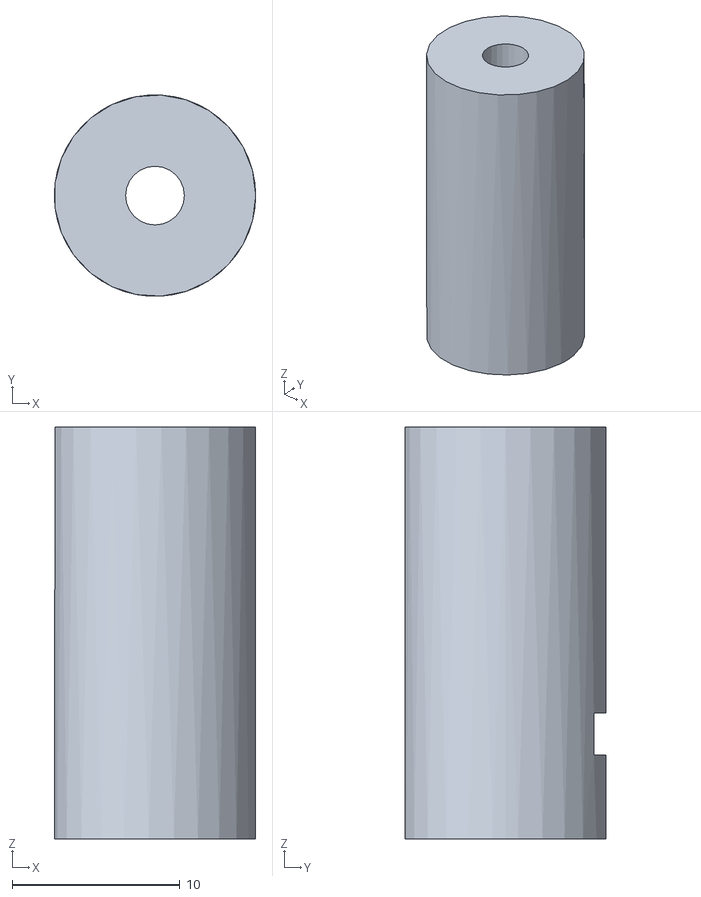
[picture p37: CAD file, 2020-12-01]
stl/Headunit/Stuetze Frontplatte.STL
12.0 x 12.0 x 24.5

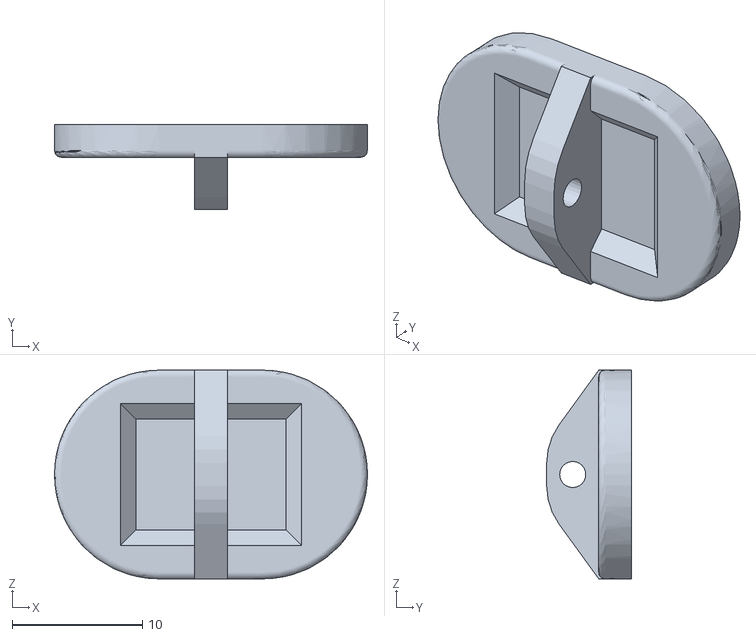
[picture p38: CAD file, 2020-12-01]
stl/Schwerpunkt/Tragflaechenauflagen (beweglich).STL
24.0 x 6.49 x 16.0

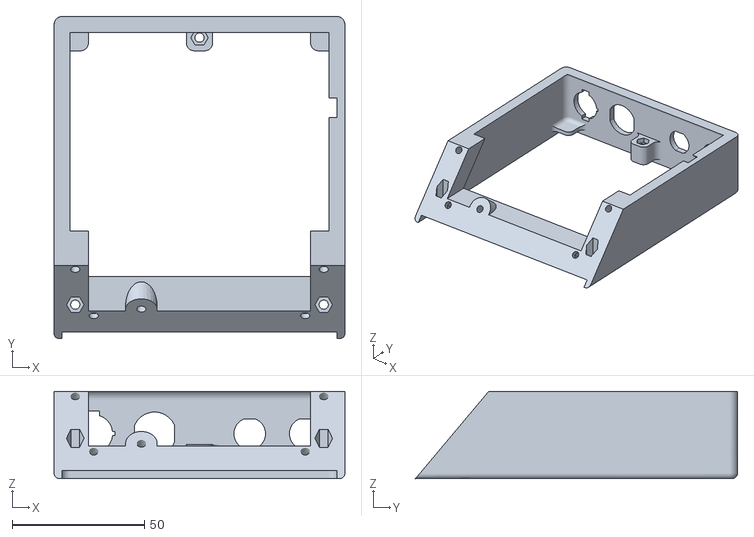
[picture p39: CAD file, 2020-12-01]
stl/Headunit/Grundrahmen.STL
110.0 x 121.8 x 33.0

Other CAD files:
stl/Winkelmessung/Deckel S1.STL
stl/Schwerpunkt/Gehaeusedeckel Unterseite.STL
stl/Headunit/Deckelplatte.STL
stl/Schwerpunkt/Gehaeusedeckel links.STL
stl/Schwerpunkt/Hinterer Modell-Traeger.STL

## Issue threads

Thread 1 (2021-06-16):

LCD bleibt weiß

alzi7, 2021-06-16:
Hallo,
ich habe leider das Problem das mein Display weiß bleibt.
Habe eins mit gelben Beinen HX8347 und ein mit schwarzen RM68090, das schwarze ist aus deimen Link von Banggood.
Der Kompieler läuft ohne Fehler durch. Habe auch schon beide hex Dateien und alle 4 TTFTYPEN durchprobiert, leider ohne Erfolg.
Kannst du mir vielleicht weiterhelfen?
Vielen Dank im Voraus

strgaltdel, 2021-06-16:
Ich kehre zurück am 28.06.2021.

Guten Tag,

ich bin bis zum o.g. Termin nicht erreichbar.
In dringenden Fällen können sie telefonisch die Zentrale unter 02173 950-5 erreichen und sich mit
dem jeweils zuständigen Kollegen verbinden lassen.

Danke

Hinweis: Dies ist eine automatische Antwort auf Ihre Nachricht  "[strgaltdel/3in1] LCD bleibt weiß
(#1)" gesendet am 16.06.2021 19:39:29.

Diese ist die einzige Benachrichtigung, die Sie empfangen werden, während diese Person abwesend ist.

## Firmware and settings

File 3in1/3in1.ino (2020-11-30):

/*
###################################################################################
#######																		#######
#######		    			"3in1", a tool to measure						#######
#######	  			flap deflection, EWD & CG of flying rc gear				#######
#######																		#######
#######	      			inspired by the dedicated ardu-apps					#######
#######					 which were published on RCN & RCG					#######
#######			   thanks to all who gave valuable infor & inputs 			#######
#######																		#######
#######																		#######
#######																		#######
#######	 Rev 1.00															#######
#######	 02 DEC 2020														#######
#######	 by strgaltdel														#######
###################################################################################

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
*************************************************************************************/

#define INTRO
#define MAIN_ID 999
bool mainRefStatus = true;									// 1 = refresh screen

#include "includes_main.h"




void setup() {

  bool hx711Status = false;	
	
  Serial.begin(115200);
  /*
  eepromValues = Eeprom::getValues();						// get eeprom values
  
															// init units
  if (eepromValues.metricImpOption == 0) {					// metric:												
				unit_lenght = str_mm;
				unit_lenght2 = str_mm2;
				unit_factorLN = 1.00;						
				unit_weight = str_g;
				unit_weight2 = str_g2;
				unit_factorWG = 1.0;	
		}
  else {													// imperial		
				unit_lenght = str_inch;
				unit_lenght2 = str_inch2;
				unit_factorLN = 1.0/25.4;					
				unit_weight = str_ounce;
				unit_weight2 = str_ounce2;
				unit_factorWG = 0.035274;	
		}														
  */
  updateEEpromValues();										// get eeprom values
  tftinit();											  	// init tft
  Serial.println("Rev 1.00  29.Nov 2020");
  
  frontCell.begin(FRONT_CELL_DOUT, FRONT_CELL_SCK);  		// init load cells (ADA)

	
  if (frontCell.wait_ready_timeout(200)) {
    long reading = frontCell.read();
    Serial.println("HX711 front reading.. ");
	hx711Status = true;
    } 
  else {
    Serial.println("HX711 front not found.");
    }
    
  rearCell.begin(REAR_CELL_DOUT, REAR_CELL_SCK);
  
   if (rearCell.wait_ready_timeout(100)) {
    long reading = rearCell.read();
    Serial.println("HX711 rear reading.. ");
   } else {
    Serial.println("HX711 rear not found.");
	hx711Status = false;
   }
 

  if(hx711Status == true){									// init&tara if hx711 found
  
	frontCell.set_scale(eepromValues.frontScale);
	rearCell.set_scale(eepromValues.rearScale); 
  }
  
  // Initialize Imu Sensors 
  IMUsensor.init(0);										//init IMU sensor:0 (wing)
  IMUsensor.init(1);										//init IMU sensor:1	(tail)
  IMUsensor.init(2);										//init IMU sensor:2 (V-tail)
  IMUsensor.init(3);										//init IMU sensor:3 (Flap#0)
  IMUsensor.init(4);										//init IMU sensor:4 (Flap#1)
  
}

void dispHeader() {

	tft.setTextSize(4);					
	tft.setTextColor(WHITE);
	tft.setCursor(tWidth*0.5 -45, tHeight*0.04);
	tft.println("3in1");
				
	tft.setTextSize(1);	
	tft.setTextColor(CYAN);
	tft.setCursor(tWidth*0.5-58, tHeight*0.16);
	tft.println("Rev 1.0 by NOWAtec");
//	tft.println("Rev 1.0, dem Paul seine");
}

void loop() {

	int i, handler;									// handler is used to control menue options
	Button  but[6];									// some buttons have to be used in this menue
	int numButtons = 2;								// number of buttons on this screen, starting with 0
	
	// description of buttons:
	but[0].type 		= BUT_XXL;					// button size
	but[0].colour		= BUTCOLOUR;				// button colour
	but[0].label		= str_CGSCALE;				// label
	but[0].labelcolour 	= BUTTXTCOLOUR;				// label - colour
	but[0].xpos			= 30;						// X position
	but[0].ypos			= 100;						// Y position
	
	// and for the next buttons we go short:
	but[1] = {BUT_XXL, BUTCOLOUR, 	str_EWDSCALE, 	BUTTXTCOLOUR, 30, 170};	
	but[2] = {BUT_XXL, BUTCOLOUR, 	str_DEFLSCALE, 	BUTTXTCOLOUR, 30, 240};
	
	but[3] = {BUT_XXL, BUTCOLOUR, 	str_Intro_1, 	BUTTXTCOLOUR, 30, 100};	
	but[4] = {BUT_XXL, BUTCOLOUR, 	str_Intro_2, 	BUTTXTCOLOUR, 30, 170};	
	but[5] = {BUT_XXL, BUTCOLOUR, 	str_Intro_3, 	BUTTXTCOLOUR, 30, 240};
	


	
	

	// draw Buttons 		************

	if (mainRefStatus == true) {
	  tft.fillScreen(BACKGROUND);
	  if (introFlag) {
	  // intro
	    #ifdef INTRO
		DrawButton(but[3]);
		delay(1600);		
		tft.fillRect(0,100,tWidth,55, BLACK);
		DrawButton(but[4]);
		delay(1600);		
		tft.fillRect(0,170,tWidth,55, BLACK);
		DrawButton(but[5]);
		delay(1600);
		introFlag=false;
	    #endif 
	  }
	  
	  for (i=0; i<=2; i++) {
		DrawButton(but[i]);
	  }
	  mainRefStatus = false;			// at this moment no screen refresh needed
	  dispHeader();
	}
	
	handler = MAIN_ID;				// init handler

	
	
														//  *****    get touched Button:  **********		
	if ( checkPressed()==true){							// touch was pressed ?
		for (i=0; i<=numButtons; i++) {					// if yes, check if it was a button
			if (checkButton(but[i],i)) {				
				handler = i;							// if button was pressed, return handler
				mainRefStatus = true;					// need screen to refresh 
			}
		}		
	}
	
	// handler				*************
	switch (handler)
	{
		case 0:
			Serial.println("Jump to cg scale");
			cg_main();		//jump to incidence subroutine
			break;
		case 1:
			Serial.println("Jump to incidence meter");
			incidence();	//jump to incidence subroutine
			break;

		case 2:
			Serial.println("Jump to deflection");
			deflection();	//jump to deflection subroutine
			break;
			
	handler = MAIN_ID;
	}

 }


 
 

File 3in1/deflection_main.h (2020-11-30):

/* ***************************************************************************************
this code is part of "3in1.ino", an app to measure cg, incidence & deflection of rc models

##########################################################################################
##																						##
##  header file: 	deflection_main.h													##
##  content:		read IMU deflection values and display data on screen				##
##  date:			21.Nov 2020															##
##  rev.:			1.0																	##
##  by strgaltdel																		##
##########################################################################################


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
*************************************************************************************/


#ifndef DEFLECTION_MAIN_H
#define DEFLECTION_MAIN_H


#include "includes_main.h"
#include "deflection_flap.h" 					// sub-menue setting flapwidth


#ifndef MAIN_VARS
#define MAIN_VARS
	float avSum1, avSum2, avCounter;				// sum up read values for building average
#endif



#ifndef IMUSENSOR
	#define IMUSENSOR
	AngleSens IMUsensor = AngleSens();			// init class IMUsensor
	Isensor IMU_0, IMU_1;						// init struct IMU  (Angle values sensor:0 & 1)
	#include "imu_cal.h"						// calibrate IMU										## app coding


// define vars used by angle calculation

float angle1;									// averaged value imu0
float angle2;									// averaged value imu1
float relative1;                  				// for zeroing
float relative2;                  				// for zeroing
float rad1;										// rad imu0
float rad2;										// rad imu1



#endif											

#define DIFF_OK	0.65							// angle difference between Flaps which is OK 

/*************************************************************************************/
/*****************    	selection which IMU should be calibrated           ***********/
/*************************************************************************************/

int select_imu()
{
	int i;
	int handler = 99;

	// define buttons for this routine
	Button but_sub2[5];
	int numButtons = 1;
	but_sub2[0] = {BUT_XXL, 	BUTCOLOUR, 	str_imuFlap0, 		BUTTXTCOLOUR, 		tWidth* 0.1,	tHeight* 0.4};	
	but_sub2[1] = {BUT_XXL, 	BUTCOLOUR, 	str_imuFlap1, 		BUTTXTCOLOUR, 		tWidth* 0.1,	tHeight* 0.7};	


	tft.fillScreen(BACKGROUND);
	// draw Buttons 						************
	for (i=0; i<=numButtons; i++) {
		DrawButton(but_sub2[i]);
	}
		
	while (handler  > numButtons)
	{	
		
														//  *****    get touched Button:  **********		
		if ( checkPressed()==true){							// touch was pressed ?
			for (i=0; i<=numButtons; i++) {					// if yes, check if it was a button
				if (checkButton(but_sub2[i],i)) {				
					handler = i;							// if button was pressed, return handler
					#ifdef DEBUG
						Serial.print("pressed  ");Serial.println(but_sub2[i].label);
					#endif
				}
			}		
		}

		
	}
	return(handler);
}

	
	
	
/*************************************************************************************/
/*****************    	main function / display flap deflection           ************/
/*************************************************************************************/


void deflection()
{
// 	#############################################    definition /declaration  block     ####################################################
	/*****************    	struct for layout (columns, offsets etc..)           ************/
	typedef struct {
		int col1;			// left disp column (values)
		int col2;			// right disp column (values)
		int center;			// center column (values)
		int row1;			// center column (values)
		int row2;
		int row3;
		int xOffs1;
	} layDefl;
	layDefl layout;

	
	
	Button but_sub[5];
	int numButtons = 4;
	int i, handler, imu_number;
	int deflStatus = 1;
	bool update_buttons = true;
	bool update_screen = true;
	char strDummy[20];

	int valueSize = 3;							// char size of measured values
	int diffSize = 5;							// char size of deltaValue

	float throw1;								// throw imu0
	float throw2;								// throw imu1
	int up1;                        			// 1 -> up, 2 -> down
	int up2;                        			// 1 -> up, 2 -> down


	unsigned long startMillis = 0;  			// used to calculate lcd refresh
	unsigned long actualMillis  = 0;			// used to calculate lcd refresh


												// float to char dummies (dtostrf)
												// used to "overwrite" old values on screen without filling area black
												// (performancewise):
	char old1[20], old2[20], old3[20], old4[20], old5[20], old6[20];
	char new1[20], new2[20], new3[20], new4[20], new5[20], new6[20];
	
	dtostrf(0,5,1,old1);						// definitions for 1st run
	dtostrf(0,5,1,old2);
	dtostrf(0,5,1,old3);
	dtostrf(0,5,1,old4);
	dtostrf(0,5,1,old5);
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

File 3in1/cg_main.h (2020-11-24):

/* ***************************************************************************************
this code is part of "3in1.ino", an app to measure cg, incidence & deflection of rc models

##########################################################################################
##																						##
##  header file: 	cg_main.h															##
##  content:		main menue cg scale													##
##  date:			30 Jan 2020															##
##  rev.:			1.0																	##
##  by strgaltdel																			##
##########################################################################################


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
*************************************************************************************/



#ifndef CG_MAIN_H
#define CG_MAIN_H


#include "includes_main.h"

#include "cg_conf.h"								// menue cg configuration
#include "cg_calibrate.h"							// menue cg calibration									
#include "cg_raw.h"									// menue cg raw values		

	
	
/*************************************************************************************/
/*****************    	main function / display cg readings               ************/
/*************************************************************************************/


void cg_main()
{
// 	#############################################    definition /declaration  block     ####################################################

	/*****************    	struct for layout (columns, offsets etc..)           ************/
	typedef struct {
		int col1;								// left disp column (values)
		int col2;								// right disp column (values)
		int center;								// center column (values)
		int row1;								// center column (values)
		int row2;
		int row3;
		int xOffs1;
	} layDefl;
	layDefl layout;

	Button but_sub[5];							// declare buttons
	int numButtons = 4;							// number of buttons on this screen, starting with 0
	int i, handler;
	bool cgStatus = true;
	bool update_buttons = true;
	bool update_screen = true;
	char strDummy[20];




	unsigned long startMillis = 0;  			// used to calculate lcd refresh
	unsigned long actualMillis  = 0;			// used to calculate lcd refresh

	
												// float to char dummies (dtostrf)
												// used to "overwrite" old values on screen without filling area black
												// (performancewise):
												
	char old1[20] = " ";						// avoid foo fighters in first loop
	char old2[20] = " ";
	char old3[20], old4[20], old5[20], old6[20];
	char new1[20], new2[20], new3[20], new4[20], new5[20], new6[20];

	
	int valueSize  = 5;						// char size of cg
	int valueSize2 = 4;						// char size of weight
	
	int xCol1 = tWidth * 0.08;				// left disp column ( cg )
	int xCol2 = tWidth * 0.55;				// right disp column (weight )
	int xCol3 = tWidth * 0.4;				// center column (values)
	int yLine1 = tHeight * 0.07;			// row1 ...
	int yLine2 = tHeight * 0.2;
	int yLine3 = yLine2  + (tHeight*0.09);
	int val_xOffs1 = 20;
	int val_xOffs2 = 0;
	const int COLOUR2 = LIGHTGREY;
	
	#ifdef TESTRES							// could be used for more cg value resolution; not evaluated
	 valueSize  = 5;						// char size of cg
	 valueSize2 = 3;						// char size of weight
	 xCol1 = tWidth * 0.02;					// left disp column ( cg )
	 xCol2 = tWidth * 0.7;					// right disp column (weight )
	 val_xOffs2 = -30;
	#endif
	
	// define buttons for this screen
	// row1
	but_sub[0] = {BUT_XL, 	BUTCOLOUR, 	str_TARA	,	BUTTXTCOLOUR, tWidth*0.32, tHeight * 0.65};	
	but_sub[1] = {BUT_MID, 	BUTCOLOUR, 	str_CG_raw,		BUTTXTCOLOUR, 1,				tHeight * 0.65};
	//row2	
	but_sub[2] = {BUT_S, 	RED, 		str_CALIBRATE, 	BUTTXTCOLOUR, 1, 				tHeight * 0.83  +15};
	but_sub[3] = {BUT_XL, 	GREEN, 		str_BACK, 		BUTTXTCOLOUR, tWidth*0.32, tHeight * 0.83};
	but_sub[4] = {BUT_MID, 	BUTCOLOUR, 	str_CONFIG,		BUTTXTCOLOUR, tWidth*0.75, tHeight * 0.83};


	// some scale vars
	static MovingAverage avgFront(CELL_SAMPLE_ITERATIONS);				// averaged measurement
	static MovingAverage avgRear(CELL_SAMPLE_ITERATIONS);				// need https://github.com/sofian/MovingAverage
	
	float frontUnits;													// front raw measurement
	float rearUnits;													// rear raw measurement
	float totalWeight;													// sum: front + rear (raw)
	float totalForce;													// force: weight x distance
	float cg;															// center of gravity
	
	startMillis = millis();												// init refresh counter							

	frontCell.tare(CELL_SAMPLE_ITERATIONS);								// tare at start
	rearCell.tare(CELL_SAMPLE_ITERATIONS);	
	
  while (cgStatus == true)
  {
	handler = MAIN_ID;			// init handler to accept new user inputs
    //#############################################    read & calc block     ##############################################################
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

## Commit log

2020-11-06 more imu methods
2020-12-01 Rev 1.0
    [Bodenplatte.STL, Deckel S0.STL, Deckel S1.STL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]

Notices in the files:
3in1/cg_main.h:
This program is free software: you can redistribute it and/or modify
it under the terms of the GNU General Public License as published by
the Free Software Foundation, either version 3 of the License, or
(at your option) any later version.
